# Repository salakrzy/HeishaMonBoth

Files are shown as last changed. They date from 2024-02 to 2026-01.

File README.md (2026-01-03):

# HeishaMonBoth Ver 3.9_a changelog

* Stability and performance improvements.

* When the RJ45cable i connected and the Ethernet interface has got IP address the WiFi interface is go down to reduce power consumpion.

* Automatic selection of a strongest signal if the network uses APs with the same SSID or the network is of the MESH type.

* Changing the flash memory partition table to follow backtrace errors messages.

* Compatibile Integration ver 3.9 with HomeAssistant  [https://github.com/kamaradclimber/heishamon-homeassistant/](https://github.com/kamaradclimber/heishamon-homeassistant/)

## 485 Modbus

* To reduce modbus errors now Modbus port run on hardware UART and logingmessages are redirected to SoftwareSerial port.

* On begining the RxD0 and TxD0 are used to UART0 Rx and Tx. When checkbox Modbus in settings is set to On the hrdware UART0 is redirected to GPIO23 (Rx) and GPIO21(Tx).

* The register definitions of the MOdbus device are user-configurable and stored in the ESP32 flash memory.
  You can download MOdbusxx.json file with your own counters definition to the flash memory in Modbus section.

## New and Old PCB

This 3.9_a version is compatible with both the old and new PCB versions. Settings allows you to configure which board version the software will work with.

Default configuration is set to newPCB.

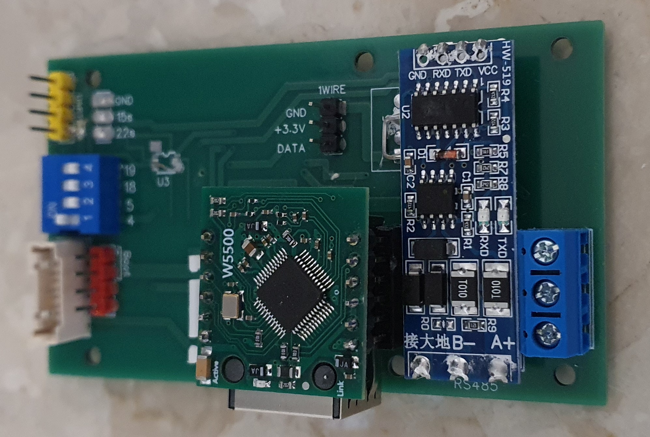
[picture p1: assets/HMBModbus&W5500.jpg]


#### The new PCB works with:

* W5500 Ethernet module
* RS485 to TTL module
* Dallas DS1820 temperature sensor
* I2C Display (only MODBUS version under construction)
* two S0 pins

#### The new board can be:

* powered via USB-C
* mounted in a dedicated enclosure (stl files are in Doc section )
* mounted in a 54mm DIN rail enclosure

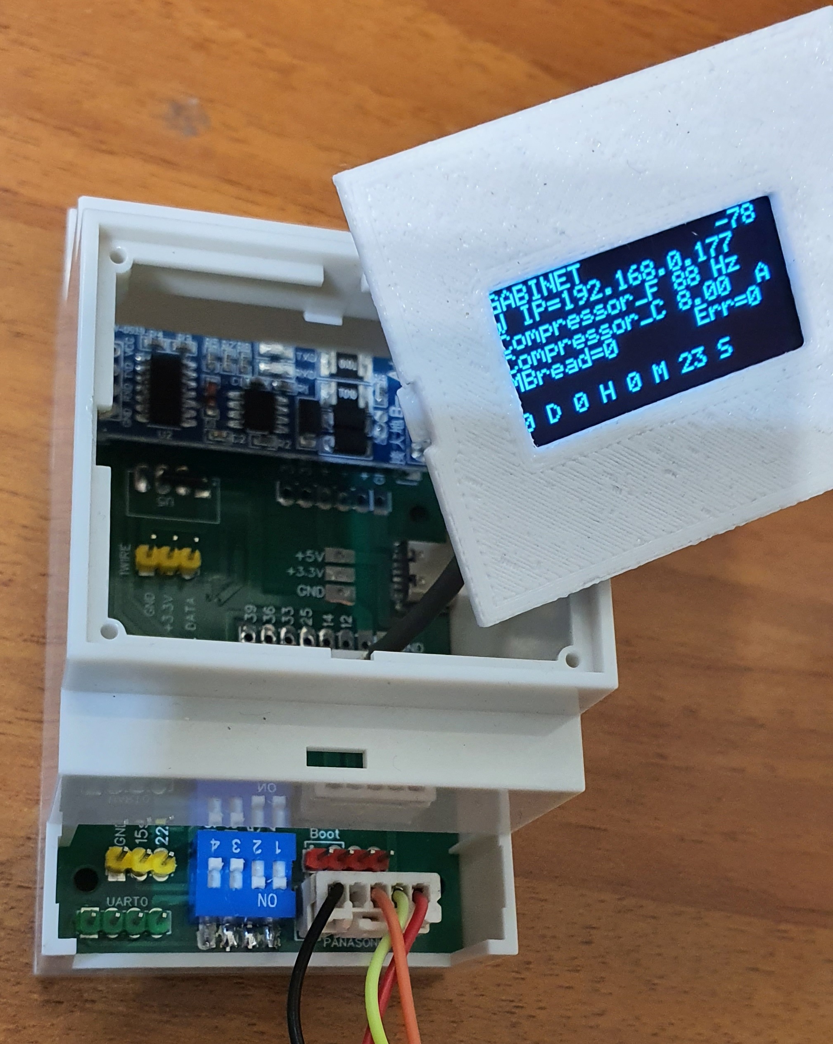
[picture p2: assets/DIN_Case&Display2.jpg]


#### The new PCB with HMBModbus software can communicate with wall control panels via Modbus.

The HMBModbus software has implemented the IntenesisBox PAW-AW-MBS-H interface messages and full TOP and SET HeishaMon Topics.
The description of the Modbus registers that can be used can be found in the /DOC/newPCB tab.

# HeishaMonBoth Ver 3.9 changelog

### ## Version 3_9 supports 12 new parameters.

"Z1_Valve_PID",            //TOP127
"Z2_Valve_PID",            //TOP128
"Bivalent_Control",        //TOP129
"Bivalent_Mode",           //TOP130
"Bivalent_Start_Temp",     //TOP131
"Bivalent_Advanced_Heat",  //TOP132
"Bivalent_Advanced_DHW",   //TOP133
"Bivalent_Advanced_Start_Temp",//TOP134
"Bivalent_Advanced_Stop_Temp",//TOP135
"Bivalent_Advanced_Start_Delay",//TOP136
"Bivalent_Advanced_Stop_Delay",//TOP137
"Bivalent_Advanced_DHW_Delay",//TOP138

### ## Version 3.9 supports meters with MODBUS interface.

The user can define support for up to 4 MODBUS devices. Details on how to connect the interface and define register reading are included in the ModbusDoc folder. Currently, readings are visible in the Console tab and sent to the MQTT server. Readings are performed every 10 seconds (MODBUS_READ_TIMER = 10).If there are any needs for changes, please report them in Issues.

---

# HeishaMonBoth Ver 3.8 changelog

## GPIO

The new PCB version provides additional PINs GPIO (05, 12,14, 18,19, 21 Schmitt trigger,25, 33, 34, 35).
The S0 and S1 Counters  (GPIO 22 and 23) are Schmitt triggered.\

## Upgrade from old versions

New firmware is  backward compatible with the previous PCB version. You can install version 3.8 on the previous PCB version, of cource the functionalities requiring access to the added GPIOs will not be available.
After upgrading firmware to version 3_8 , you should short the "boot" pins for 10 seconds to delete the old configuration settings file. Switch power off, leave boot jumper and after power restart, the new configuration file will be created with a structure compatible with firmware version 3_8 . The boot jumper you can see at the [picture](https://github.com/salakrzy/HeishaMonBoth/blob/main/Doc/Board%20set%20in%20Boot%20or%20Reset%20mode.jpg) in Doc directory.
You can delete old configuration also from the Settings web page, selecting [Factory Reset](https://github.com/salakrzy/HeishaMonBoth/blob/main/Doc/HMBv3_8Stetting2.png) option.
The new file has default parameter settings so you should configure the board again according to your settings.

## Reset configration

If you have problem with WiFi setting after e.g. replace router you can reset the old configuration in this same way.

## Version 3_8 supports 13 new model configurations

"IDU:WH-SDC0509L3E5 ODU:WH-WDG09LE5", //38
"IDU:WH-SDC12H9E8 ODU:WH-UD12HE8", //39
"IDU:WH-SDC0309K3E5, ODU:WH-UDZ07KE5", //40
"IDU:WH-ADC0916H9E8, ODU:WH-UX16HE8", //41
"IDU:WH-ADC0912H9E8, ODU:WH-UX12HE8", //42
"WH-MXC16J9E8", //43
"WH-MXC12J6E5", //44
"IDU:WH-SQC09H3E8, ODU:WH-UQ09HE8", //45
"IDU:WH-ADC0309K3E5 ODU:WH-UDZ09KE5", //46
"IDU:WH-ADC0916H9E8, ODU:WH-UX12HE8", //47
"IDU:WH-SDC0509L3E5 ODU:WH-WDG07LE5", //48
"IDU:WH-SXC09H3E5, ODU:WH-UX09HE5", //49
"IDU:WH-SXC12H9E8, ODU:WH-UX12HE8", //50

## Version 3_8 supports 12 new parameters.

"Water_Pressure",          //TOP115
"Second_Inlet_Temp",       //TOP116
"Economizer_Outlet_Temp",  //TOP117
"Second_Room_Thermostat_Temp",//TOP118
"Bivalent_Heating_Start_Temperature",//TOP119
"Bivalent_Heating_Parallel_Adv_Starttemp",//TOP120
"Bivalent_Heating_Parallel_Adv_Stoptemp",//TOP121
"Bivalent_Heating_Parallel_Adv_Start_Delay",//TOP122
"Bivalent_Heating_Parallel_Adv_Stop_Delay",//TOP123
"Bivalent_Heating_Setting",//TOP124
"2_Zone_mixing_valve_1_opening",//TOP125
"2_Zone_mixing_valve_2_opening",//TOP126

## Home Assistant

This version is compatible with ver 1.13.7 HA Integration [kamaradclimber](https://github.com/kamaradclimber/heishamon-homeassistant)

## RJ45 Ethernet functionality

The 3.8 version support [W5500](https://github.com/salakrzy/HeishaMonBoth/blob/main/Doc/Connecting%20%20W5500%20Ethernet%20module.PNG) module to connetct via RJ45 ethernet cable network
//W5500 ETH pins	-->	ESP32 GPIO
#define ETH_CS    -->      25
#define ETH_IRQ    -->     33
#define ETH_RST    -->     35

//W5500  SPI pins	-->	ESP32 GPIO
#define ETH_SPI_SCK   -->  14
#define ETH_SPI_MISO  -->  34
#define ETH_SPI_MOSI  -->  12

## Notes

Some ESP32 processor versions have only 1 core instead of 2. You have to pay attention to this because the HeishaMonBoth software requires 2 processors. I bought a 1-core processor and wasted some time trying to figure out why the board resets on startup.
OpenTherm and Optional PCB and Rules features should work but havn't been tested.
Oficial published Librrary OneWire has the error in file **OneWire_direct_gpio.h** It is described there https://github.com/PaulStoffregen/OneWire/pull/134/commits/da50f912a8282dacf381d006e75e0141df2a931c)
I recomend use the file **OneWire_direct_gpio.h** from direcotry OneWire\util.

---

# HeishaMonBoth 3.2 changelog

This is a HeishaMon modification allowing parallel work of Panasonic Web, local reading via MQTT and integration with HomeAssistant.
Funtionality of this version fulfil the HeishaMon release v3.2.3
This solution works on ESP32.
This version of the software does support Dallas sensors and two S0 counters.
Integration with HomeAssistant is identical to the original HeishaMon interface. https://github.com/kamaradclimber/heishamon-homeassistant/

Since not all esp32 modules (e. g. esp32u) have IO9 and IO10 outputs and lack of these outputs on DEV boards,
I decided to redesign the PCB and adjust the program code. The new PCB has e few modifications improving functionality.
The program code is adapted to the change of the board and has fixes for the stability of work.
In the /piotools directory there is a simple program HP_Panasonic_Simul.ino that can be uploaded e. g. on Arduino Nano for test.

# Good Luck

IMPORTANT !!!!!!! put your sensitive data to platformio_user_env_sample.ini and rename to platformio_user_env.ini

Special thanks to :
Igor Ybema https://github.com/Egyras/HeishaMon
and
Alexander Gregor-Samosir https://github.com/gregor-samosir/HeishaMonKaskade
for their projects that inspired me to write this modification.

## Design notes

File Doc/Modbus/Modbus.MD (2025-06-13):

# Modbus is the new module of HeishaMonBoth interface for RTU Modbus devices like Power Meter, Water Meter e.g.

This Module use additional board to convert the RS485 RTU Modbus to RS232 Serial UART signals.

By default the MODBUS converter interface use the hardware UART0 port, however this requires block in the Settings  the sending of logs to this port

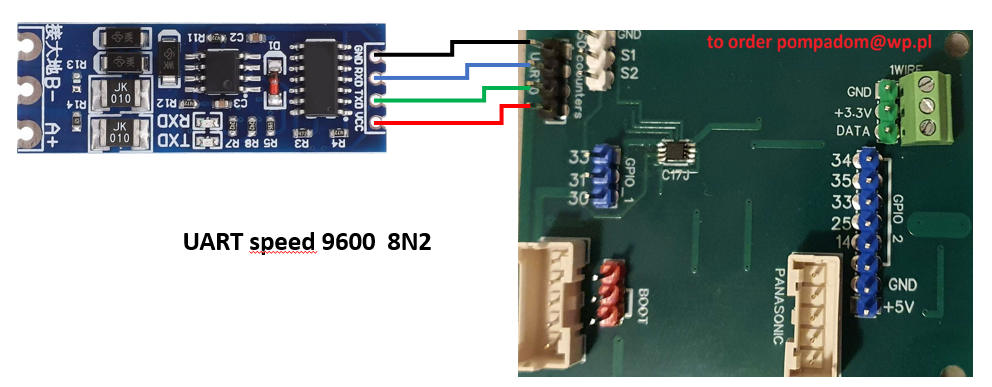
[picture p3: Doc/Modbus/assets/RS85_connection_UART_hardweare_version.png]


> 

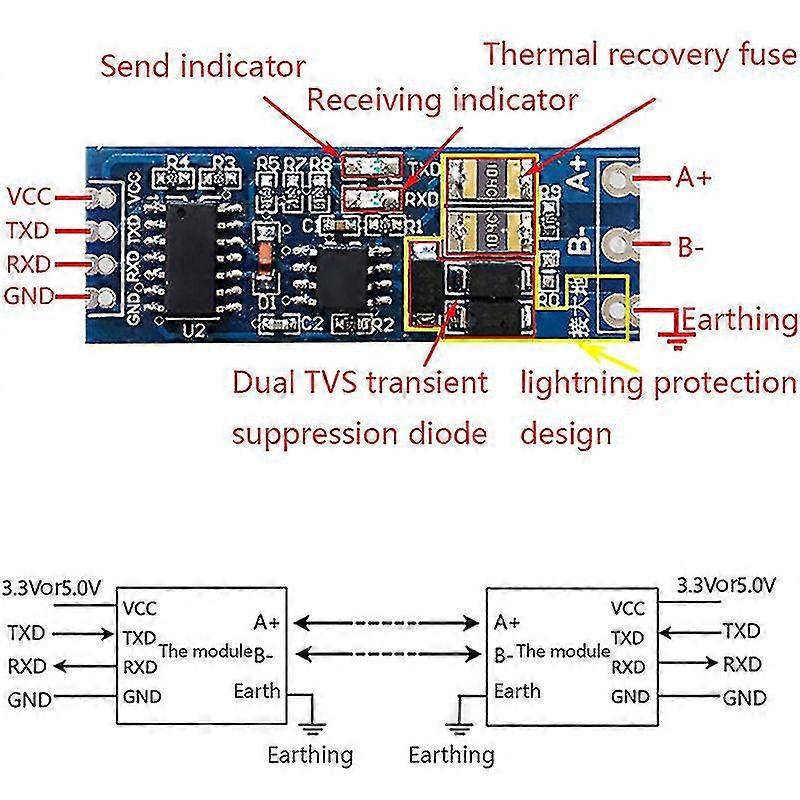
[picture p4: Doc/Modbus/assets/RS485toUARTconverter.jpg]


The Modbus module can use the "EspSoftwareSerial" librrary to create additional serial port to connect the RS485 converter to HeishModBoth. Use SoftwareSerial need a few changes in code The transmission modbus Device parametters must be set to speed -**9600**, bits -**8**, parity -**None**, stop bits -**2** (**9600 8N2** ) and modbus device address must be set this same as the parameter "devAddress" in Modbusxxx.json config file. The software solution seems to be not enough efficient for communication at a speed of 9600 bps. The SoftwareSerial solution from time to time return error modbus device reading when ESP32 processor is bussy by other process eg. webserwer or acounting S0 impulses.
Example how use ESPSeoftwareSerial librrarry is explained in branch ModbusSoft.
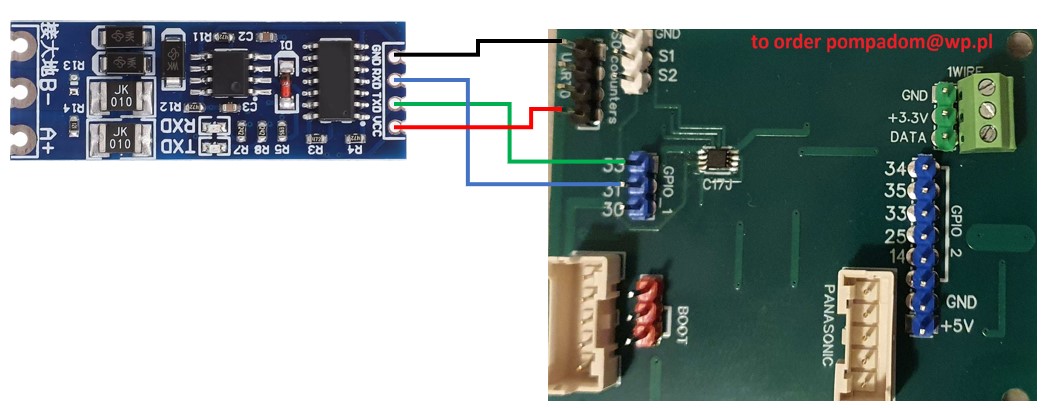
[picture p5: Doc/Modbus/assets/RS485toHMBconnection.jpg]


From the 3.8.1 verison, HeishaMonBoth allows send and handling up to 4 queries to the same device or up to 4 different Modbus devices connected to this same bus, depending what the device address is set by parameter "devAddress". Each Modbusxxx.json file define one query and his name must start from Modbus  word eg Modbus12.json, Modbus3new,json. Each query allows handling up to 16 measured values from the device response. So you can read 16 values from each 4 different devices, 64 values from 1 device or any other combinations defined by the user. The user can define queries for non-standard devices by himself using the description of how to create and upload modbusxxx.json files to the board. The software supports up to 4 Modbusxxx.json files, if more than 4 counter definitions are uploaded only the first 4 will be used and the rest will be ignored.

For convenience and to check the correctness of the definition, it is worth using Online tools to verify the correctness of the JSON file

[**JSON-deserialize-online**](https://codebeautify.org/json-deserialize-online)

and also to serialize the JSON file to reduce the size of the definition file saved in the ESP32 processor memory.

[**JSON-serialize-online**](https://codebeautify.org/json-serialize-online)
In this directory you can find the typical JSON definition file named "Modbus1_example.json" and compact version named "modbus1.json".

In one query, you can read the number of registers defined in "numb_registers" from the address defined by the "addrstart" parameter. The registers in the response appear one after another and there can be up to 120 of them in one query. From these max 120 registers, you can select max 16 registers corresponding to the values that you want to pass to the MQTT server. Each value that is to be passed to the MQTT server has a defined parameter "address" that specifies the address of the register in the device's response.

## How to define the new modbus devices addres, queries and MQTT topics in Modbusxxx.json file

```
"addrstart": 0,			Address first register to read
"numb_registers": 59,		Number registers to read ( counted from 0 as array elements)
"mqttTopic": "L3F1946-P6",	Counter name set the device topic on MQTT server
"datasize1": 4,			Number bytes to read for one register (now only 4 for  float )
"devAddress": 5,		Modbus counter address, must be set this same on the Modbus device
"Value0": {			THIS PARAMETER CAN'T BE CHANGED
"address": 0,			register number position in Modbus device answer 
"divider": 1,			value divider 
"unit": "V",			Value units  {V,A, kWh, Hz, m3 any other this is just only description)
"name": "VoltageA"		*Value name ( Any string )*
},
"Value1": {			THIS PARAMETER CAN'T BE CHANGED
"address": 1,			register number position in Modbus device answer 
"divider": 1,			value divider 
"unit": "V",			Value units  {V,A, kWh, Hz, m3 any other - it is just only description)
"name": "VoltageB"		*Value name ( Any string )*
},
"Value2": {
"address": 2,
"divider": 1,
"unit": "V",
"name": "VoltageC"

......
"Value15": {
"address": 27,
"divider": 1,
"unit": "kWh",
"name": "Production"
}
}
```

JSON Compact serialized form look like this

```
{"addrstart":0,"numb_registers":59,"mqttTopic":"L3F1946-P6","datasize1":4,"devAddress":5,"Value0":{"address":0,"divider":1,"unit":"V","name":"VoltageA"},"Value1":{"address":1,"divider":1,"unit":"V","name":"VoltageB"},"Value2":{"address":2,"divider":1,"unit":"V","name":"VoltageC"},"Value3":{"address":3,"divider":1,"unit":"V","name":"VoltageAB"},"Value4":{"address":4,"divider":1,"unit":"V","name":"VoltageAC"},"Value5":{"address":5,"divider":1,"unit":"V","name":"VoltageBC"},"Value6":{"address":6,"divider":1,"unit":"A","name":"CurrentA"},"Value7":{"address":7,"divider":1,"unit":"A","name":"CurrentB"},"Value8":{"address":8,"divider":1,"unit":"A","name":"CurrentC"},"Value9":{"address":21,"divider":1,"unit":"W","name":"PowerA"},"Value10":{"address":22,"divider":1,"unit":"kW","name":"PowerB"},"Value11":{"address":23,"divider":1,"unit":"kW","name":"PowerC"},"Value12":{"address":24,"divider":1,"unit":"kW","name":"TotalPow"},"Value13":{"address":25,"divider":1,"unit":"Hz","name":"Frequency"},"Value14":{"address":26,"divider":1,"unit":"kWh","name":"Consumption"},"Value15":{"address":27,"divider":1,"unit":"kWh","name":"Production"}}
```

You can fulfil the Modbus1_example.json decribing your device and values and use serialize online tool to convert JSON file to the **Compact** form.

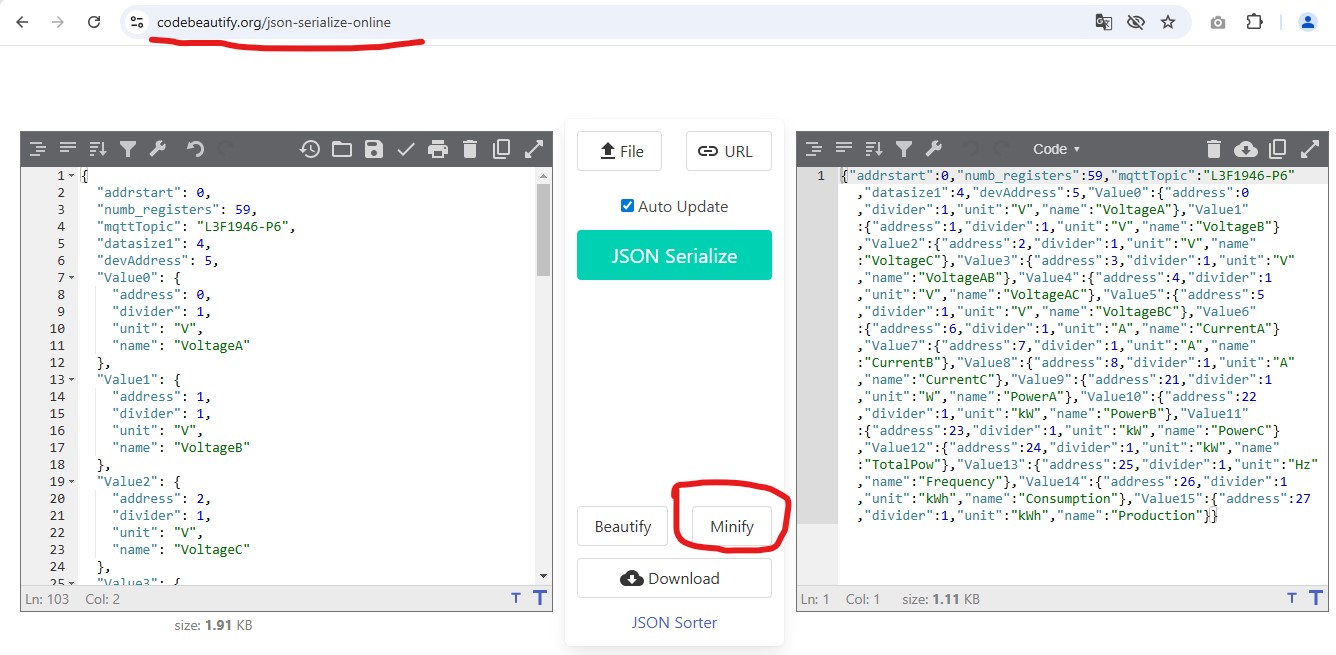
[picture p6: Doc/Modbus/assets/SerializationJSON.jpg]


Next you can upload Modbusxxx.json file using Upload function.

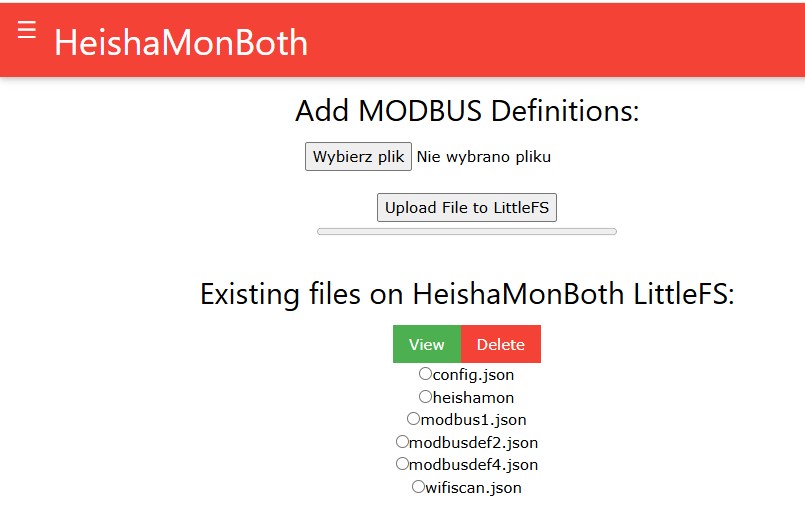
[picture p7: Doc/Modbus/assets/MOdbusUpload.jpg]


After this you can view or delete uploaded file.
If everything looks OK, You should run Reboot option to reload Modbus devices definitions. View the config.json file is forbiden to protect the wifi password but it is possibel to delete all shown files. If you delete all shown files it take this same effect as the factory reset.

##### Attention!!!

To ensure the restoration of communication with the Board in the event of continuous restarts due to an incorrectly defined counter pattern, a mechanism has been introduced to reset the settings to factory values in the event of a "Panic" error during system startup. In this case You should set the Wifi SSID, password, MQTT server and other configuration parameters.

You can view the meter readings in the console tab on the HeishaMonBoth website.

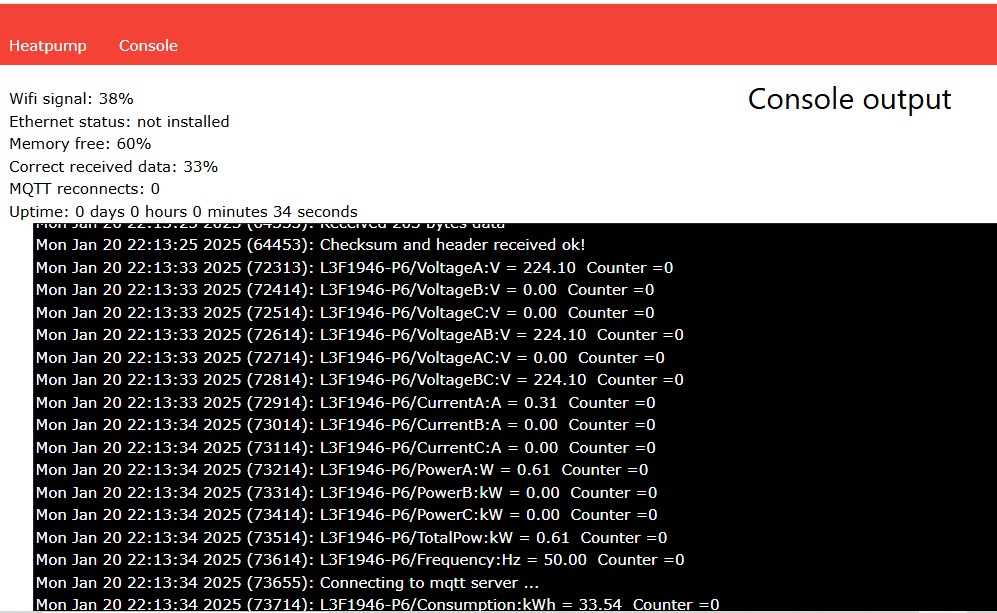
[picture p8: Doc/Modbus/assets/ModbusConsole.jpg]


You can also view them on an MQTT server.

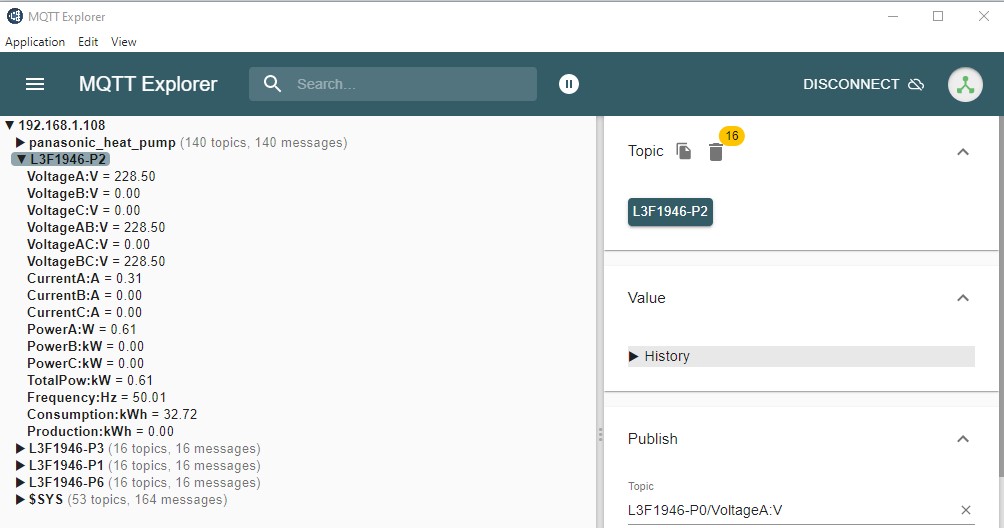
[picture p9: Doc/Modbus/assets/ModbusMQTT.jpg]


### I encourage you to report any bugs you discover or suggestions for improving the functionality of the HeishaMonBoth interface in the Issue section.

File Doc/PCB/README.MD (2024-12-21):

         
How to use：

At editor EasyEDA https://u.easyeda.com , 
Creata new project,open the document via: Top menu - File - Open - EasyEDA... , and select the json file, then open it at the editor, you can save it into a project.

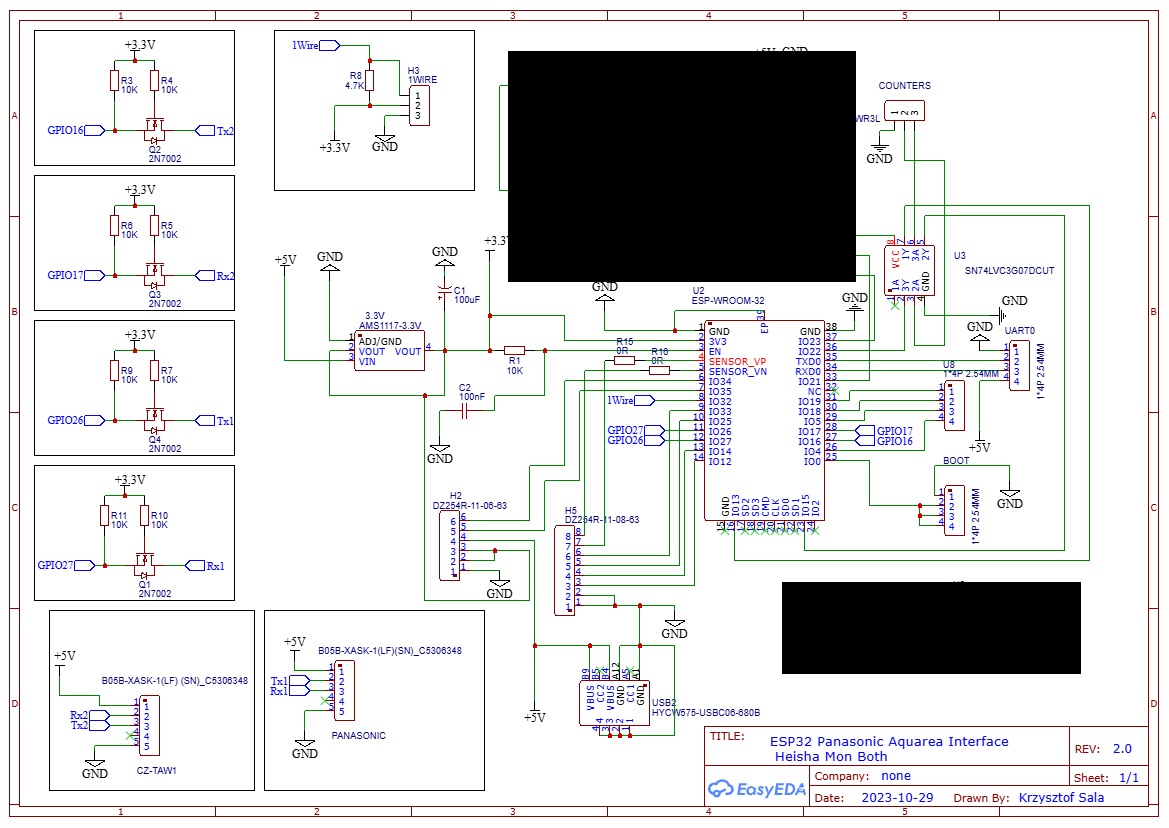
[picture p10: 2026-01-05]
Doc/new PCB/Schematic_Panasonic-aquarea-to-cztaw_W5500noRS485.jpg

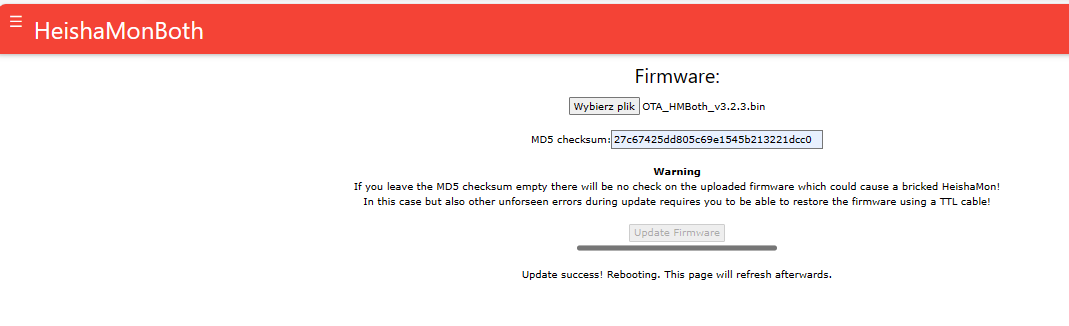
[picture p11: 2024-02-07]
Doc/HeishaMonBoth Firmware Update.png

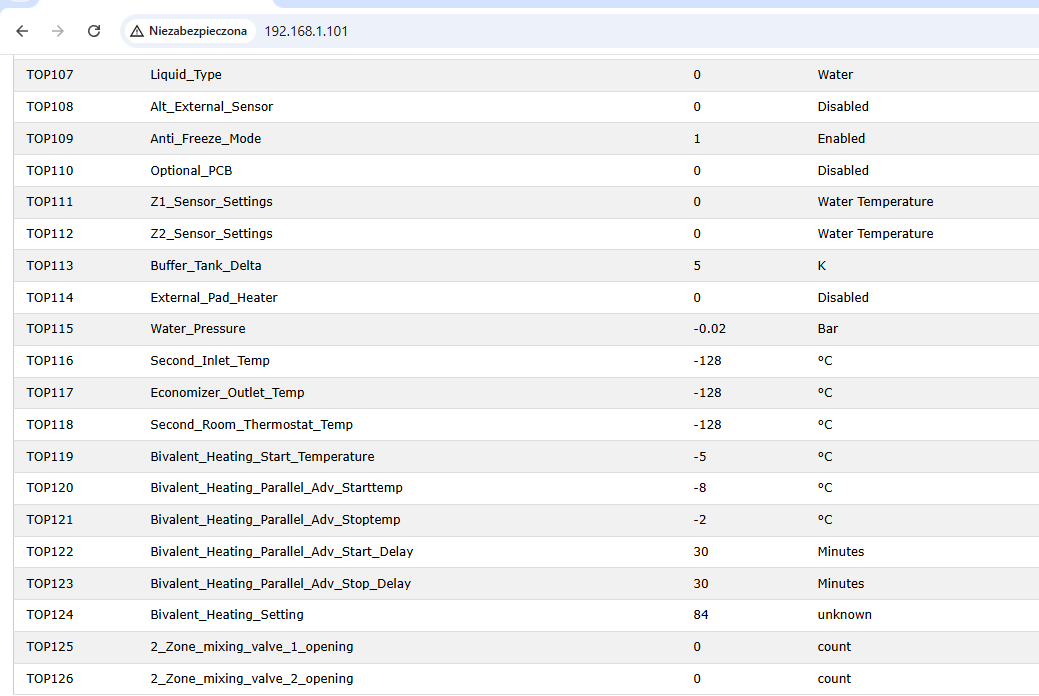
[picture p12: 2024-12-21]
Doc/HMBv3_8Topics2.PNG

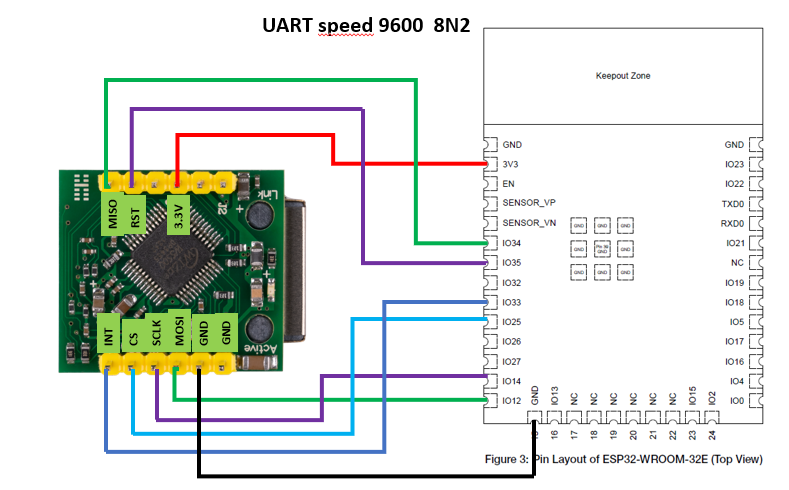
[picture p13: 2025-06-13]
Doc/new PCB/W5500 connections.png

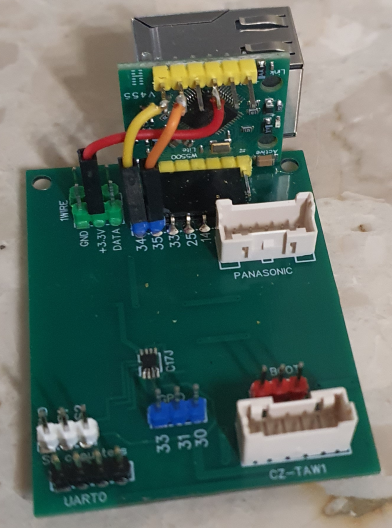
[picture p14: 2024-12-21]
Doc/W5500 Ethernet connection/Connecting W5500 Ethernet module.PNG

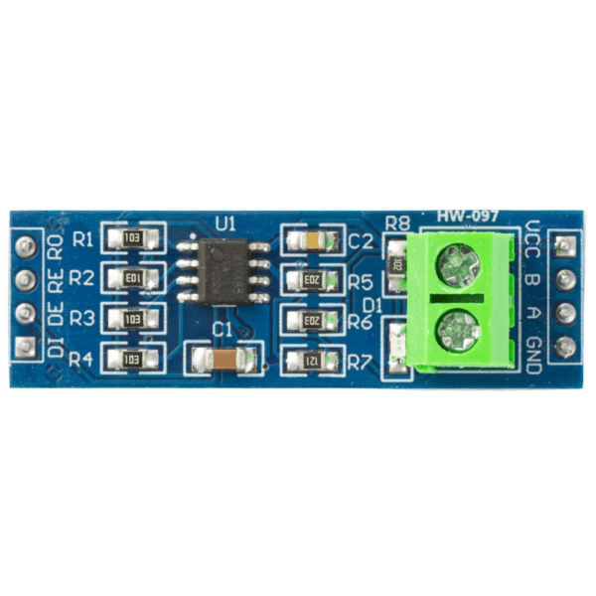
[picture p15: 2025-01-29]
Doc/Modbus/assets/RS485wDEREcontrol.png

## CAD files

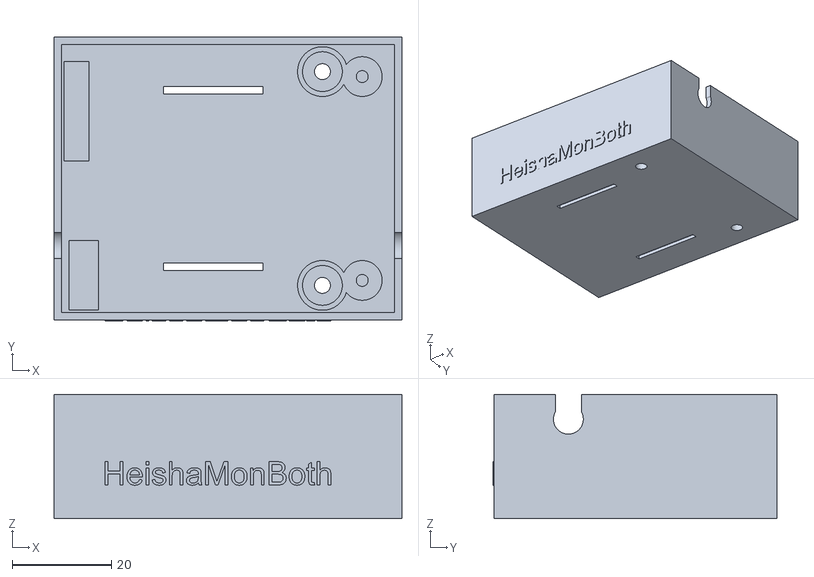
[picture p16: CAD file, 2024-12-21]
Doc/3DCase/BotHeishaMonBoth.stl
70.0 x 57.2 x 25.0

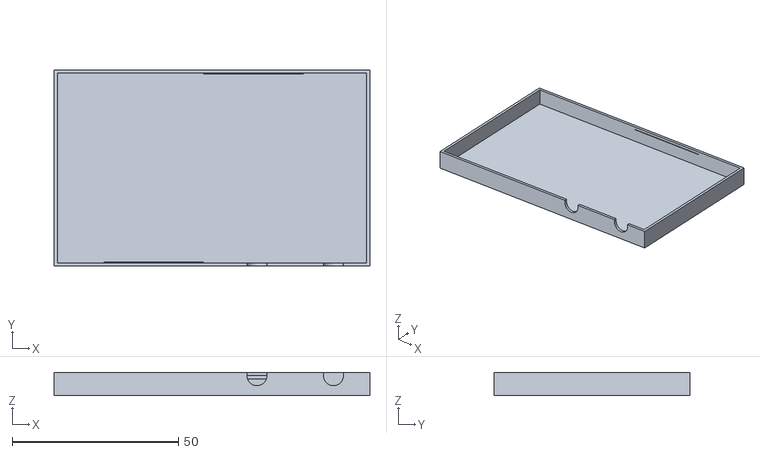
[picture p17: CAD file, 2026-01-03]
Doc/new PCB/3DCase/MHMB_Top.stl
95.0 x 59.0 x 7.00

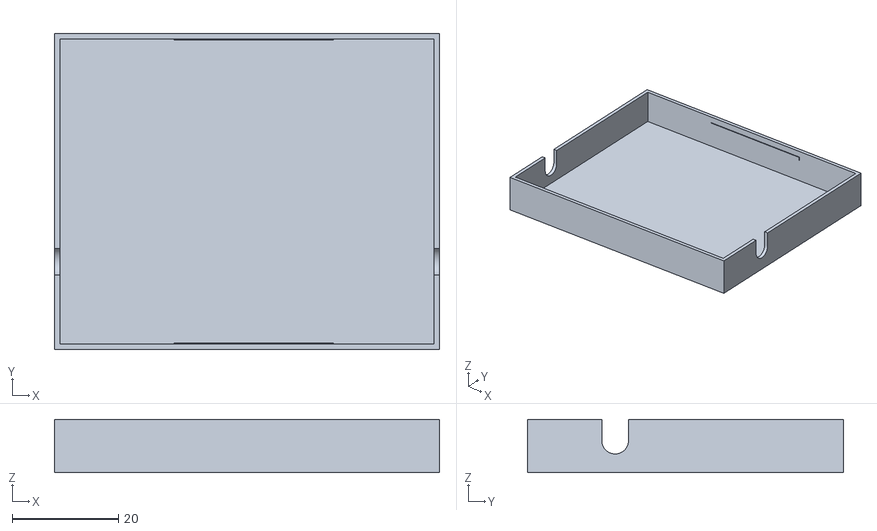
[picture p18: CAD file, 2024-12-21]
Doc/3DCase/TopHeishaMonBoth.stl
72.5 x 59.5 x 10.0

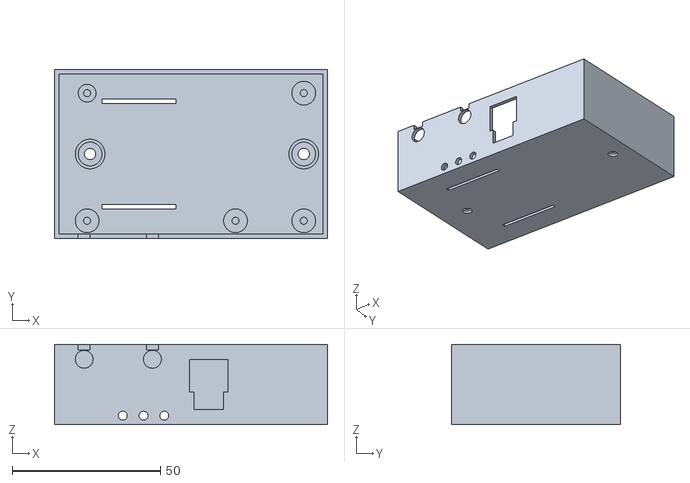
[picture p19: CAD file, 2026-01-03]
Doc/new PCB/3DCase/MHMB_Bottom.stl
92.0 x 57.0 x 27.0

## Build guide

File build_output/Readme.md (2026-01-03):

# under windows

run **OTA_flash.bat**

or
run console **CMD**
and run command

##### **esptool.exe -p COM7 --before default_reset --after hard_reset --chip esp32  write_flash --flash_mode dio --flash_size detect --flash_freq 40m 0x1000 bootloader.bin 0x8000 partitions.bin 0x10000 firmware\UART_HMBoth_v3_2_3.bin 0x00391000 littlefs.bin**

or  if you prefer Python

##### **pip install esptool**

##### **python esptool.py -p COM7 --before default_reset --after hard_reset --chip esp32  write_flash --flash_mode dio --flash_size detect --flash_freq 40m 0x1000 bootloader.bin 0x8000 partitions.bin 0x10000 UART_HMBoth_v3_2_3.bin 0x00391000 littlefs.bin**

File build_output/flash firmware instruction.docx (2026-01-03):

Flash firmware to HeishaMonBoth board

1. Upgrade file by Webserwer

Go to Setting > Firmware

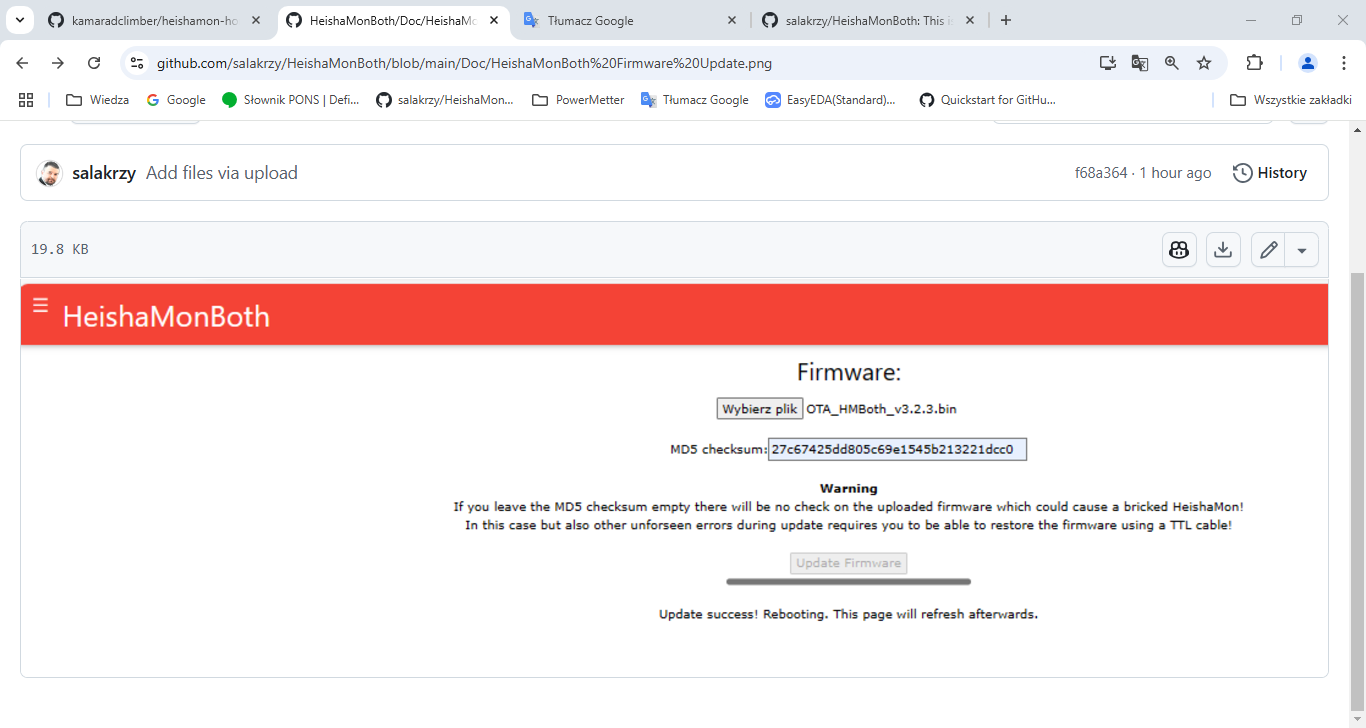
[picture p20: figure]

2. Using USB to TTL Serial converter

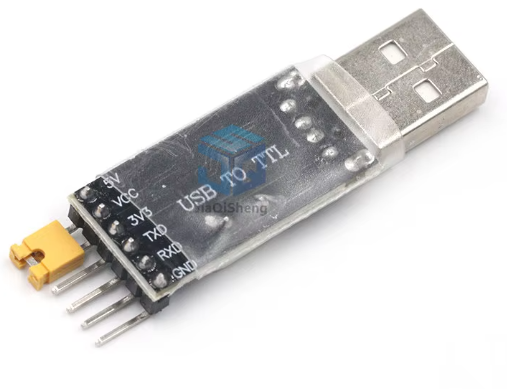
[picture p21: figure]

Copy the directory https://github.com/salakrzy/HeishaMonBoth/tree/main/build_output to your computer

Close “boot” pins on the board and connect the “ UART0” pins with USB converter.

Disconnect board from Heat pump!!!! Power will be provided by converter.

Remember Tx pin from board goes to Rx pin in converter and Rx from board goes to Tx.

Connect only the Tx, Rx, GND and +5V pins.

Go to the local directory and run OTA_flash.bat

You could see something like this

esptool.py v2.3.1

Connecting........_____....._____....._____.....___

Chip is ESP32D0WDQ5 (revision (unknown 0xa))

Features: WiFi, BT, Dual Core, Embedded Flash, VRef calibration in efuse

Uploading stub...

Running stub...

Stub running...

Changing baud rate to 921600

Changed.

Configuring flash size...

Auto-detected Flash size: 4MB

Compressed 18928 bytes to 13069...

Wrote 18928 bytes (13069 compressed) at 0x00001000 in 0.2 seconds (effective 809.8 kbit/s)...

Hash of data verified.

Compressed 3072 bytes to 157...

Wrote 3072 bytes (157 compressed) at 0x00008000 in 0.0 seconds (effective 1536.0 kbit/s)...

Hash of data verified.

Compressed 1102304 bytes to 665904...

Wrote 1102304 bytes (665904 compressed) at 0x00010000 in 9.4 seconds (effective 937.4 kbit/s)...

Hash of data verified.

Compressed 57344 bytes to 722...

Wrote 57344 bytes (722 compressed) at 0x00391000 in 0.0 seconds (effective 28671.9 kbit/s)...

Hash of data verified.

Leaving...

Hard resetting via RTS pin...

d:\...\...\Flash HeishamonBoth>pause

Press any key to continue . . .

Disconnect boot jumper and restart power

You can clear all ESP32 flash memory using command eraseesp.bat

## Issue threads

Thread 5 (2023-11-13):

Intergrate into heishamon release

IgorYbema, 2023-11-13:
Hi,
Thank you for the great work! The idea of chaining the CZ-TAW1 through heishamon is something which was thought before earlier but never implemented due to lack of GPIO's. Never had time to change the code to an ESP32 style but you have done this already. Great!

I hope you don't mind that I'll take your changes into a future release of heishamon and a redesign of the pcb to add the connector.

Misiu, 2023-11-22:
@IgorYbema any updates on this?
Also, do you plan to do PR to https://github.com/Egyras/HeishaMon or in your fork?
I just got my heat pump installed and I would like to add it to Home Assistant, so I wondering if should I wait for a new PCB or order the old one.

salakrzy, 2023-11-29:
Hello,
I'm glad you like the idea. Of course anyone who wants can use, copy and publish the result of my work on this interface. Thank you for every star clicked for this project;-)

I have a few HeishaMonBoth interface PCBs.  If you are interested in shipping, please send an email to [pompadom@wp.pl]
The assembled interface looks like in the attached pictures.

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

salakrzy, 2023-11-29:
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

IgorYbema, 2024-02-25:
Hi,
I have made a modified heishamon with this and ordered some test boards. Hopefully they work and I can use your code on them and start integrating your changes into the main project. One question, did you run into any problems with the CZTAW connected to your board and both being powered from the heatpump?

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

Closed 2023-11-29.

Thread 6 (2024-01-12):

Can not connect to Wifi with Wemos ESP32 board

ElVit, 2024-01-12:
Hi,

as the title says it I can not connect to the WiFi if I flash HeishamonBoth.
I use a Wemos ESP32 board (MH-ET LIVE MiniKit for ESP32).
If I flash a different firmware e.g. for ESPHome I can connect to my WiFi without any issues,
so my hardware should not be the problem here.

I flashed the firmware from `/build_output/firmware/ESP_USBv3.2.3.bin` with the [esptool](https://github.com/espressif/esptool) like so:
- ./esptool -p COM5 erase_flash
- ./esptool -p COM5 -b 460800 write_flash 0x00000 esp32_bootloader_v4.bin
- ./esptool -p COM5 -b 460800 write_flash 0x10000 ESP_USBv3.2.3.bin

The esp32_bootloader_v4.bin I took from the [WLED repo](https://github.com/Aircoookie/WLED/releases/download/v0.13.1/esp32_bootloader_v4.bin).

I could also flash the HeishaMonBoth firmware with the ESPHomeFlasher, but connecting to the WiFi is still failing.

Here my log output while I try to connect to the WiFi:
```
Using 'COM5' as serial port.
Showing logs:
[14:34:52]Thu Jan  1 00:00:15 1970 (15239): Previous read data attempt failed due to timeout!
[14:34:52]Thu Jan  1 00:00:15 1970 (15239): Received 0 bytes data
[14:34:52]Thu Jan  1 00:00:15 1970 (15250): sent bytes: 8 including checksum value: 185 source; 1
[14:34:52]
[14:34:52]Thu Jan  1 00:00:15 1970 (15250): Requesting initial start query
[14:34:54]Thu Jan  1 00:00:17 1970 (17251): Previous read data attempt failed due to timeout!
[14:34:54]Thu Jan  1 00:00:17 1970 (17251): Received 0 bytes data
[14:34:54]Thu Jan  1 00:00:17 1970 (17262): sent bytes: 8 including checksum value: 185 source; 1
[14:34:54]
[14:34:54]Thu Jan  1 00:00:17 1970 (17262): Requesting initial start query
[14:34:54]Thu Jan  1 00:00:17 1970 (17573): Heishamon stats: Uptime: 0 days 0 hours 0 minutes 17 seconds ## Free memory: 79% ## Heap fragmentation: % ## Max free block:  bytes ## Free heap: 226532 bytes ## Wifi: -1% (RSSI: 0) ## Mqtt reconnects: 0 ## Correct data: 0.00%
[14:34:54]Thu Jan  1 00:00:17 1970 (17594): Requesting new panasonic data
[14:34:54]Thu Jan  1 00:00:17 1970 (17594): Already sending data. Buffering this send request
[14:34:56]Thu Jan  1 00:00:19 1970 (19263): Previous read data attempt failed due to timeout!
[14:34:56]Thu Jan  1 00:00:19 1970 (19263): Received 0 bytes data
[14:34:56]Thu Jan  1 00:00:19 1970 (19274): sent bytes: 8 including checksum value: 185 source; 1
[14:34:56]
[14:34:56]Thu Jan  1 00:00:19 1970 (19274): Requesting initial start query
[14:34:58]Thu Jan  1 00:00:21 1970 (21275): Previous read data attempt failed due to timeout!
[14:34:58]Thu Jan  1 00:00:21 1970 (21275): Received 0 bytes data
[14:34:58]Thu Jan  1 00:00:21 1970 (21286): sent bytes: 8 including checksum value: 185 source; 1
[14:34:58]
[14:34:58]Thu Jan  1 00:00:21 1970 (21286): Requesting initial start query
[14:34:59]Thu Jan  1 00:00:22 1970 (22573): Heishamon stats: Uptime: 0 days 0 hours 0 minutes 22 seconds ## Free memory: 79% ## Heap fragmentation: % ## Max free block:  bytes ## Free heap: 226532 bytes ## Wifi: -1% (RSSI: 0) ## Mqtt reconnects: 0 ## Correct data: 0.00%
[14:34:59]Thu Jan  1 00:00:22 1970 (22594): Requesting new panasonic data
[14:34:59]Thu Jan  1 00:00:22 1970 (22595): Already sending data. Buffering this send request
[14:35:00]Thu Jan  1 00:00:23 1970 (23287): Previous read data attempt failed due to timeout!
[14:35:00]Thu Jan  1 00:00:23 1970 (23287): Received 0 bytes data
[14:35:00]Thu Jan  1 00:00:23 1970 (23298): sent bytes: 8 including checksum value: 185 source; 1
[14:35:00]
[14:35:00]Thu Jan  1 00:00:23 1970 (23298): Requesting initial start query
[14:35:02]Thu Jan  1 00:00:25 1970 (25299): Previous read data attempt failed due to timeout!
[14:35:02]Thu Jan  1 00:00:25 1970 (25299): Received 0 bytes data
[14:35:02]Thu Jan  1 00:00:25 1970 (25310): sent bytes: 8 including checksum value: 185 source; 1
[14:35:02]
[14:35:02]Thu Jan  1 00:00:25 1970 (25310): Requesting initial start query
[14:35:04]Thu Jan  1 00:00:27 1970 (27311): Previous read data attempt failed due to timeout!
[14:35:04]Thu Jan  1 00:00:27 1970 (27311): Received 0 bytes data
[14:35:04]Thu Jan  1 00:00:27 1970 (27322): sent bytes: 8 including checksum value: 185 source; 1
[14:35:04]
[14:35:04]Thu Jan  1 00:00:27 1970 (27322): Requesting initial start query
[14:35:04]Thu Jan  1 00:00:27 1970 (27633): Heishamon stats: Uptime: 0 days 0 hours 0 minutes 27 seconds ## Free memory: 79% ## Heap fragmentation: % ## Max free block:  bytes ## Free heap: 226532 bytes ## Wifi: -1% (RSSI: 0) ## Mqtt reconnects: 0 ## Correct data: 0.00%
[14:35:04]Thu Jan  1 00:00:27 1970 (27654): Requesting new panasonic data
[14:35:04]Thu Jan  1 00:00:27 1970 (27654): Already sending data. Buffering this send request
[14:35:06]Thu Jan  1 00:00:29 1970 (29323): Previous read data attempt failed due to timeout!
[14:35:06]Thu Jan  1 00:00:29 1970 (29323): Received 0 bytes data
[14:35:06]Thu Jan  1 00:00:29 1970 (29334): sent bytes: 8 including checksum value: 185 source; 1
[14:35:06]
[14:35:06]Thu Jan  1 00:00:29 1970 (29334): Requesting initial start query
[14:35:08]Thu Jan  1 00:00:31 1970 (31335): Previous read data attempt failed due to timeout!
[14:35:08]Thu Jan  1 00:00:31 1970 (31335): Received 0 bytes data
[14:35:08]Thu Jan  1 00:00:31 1970 (31346): sent bytes: 8 including checksum value: 185 source; 1
[14:35:08]
[14:35:08]Thu Jan  1 00:00:31 1970 (31346): Requesting initial start query
[14:35:09]Thu Jan  1 00:00:32 1970 (32633): Heishamon stats: Uptime: 0 days 0 hours 0 minutes 32 seconds ## Free memory: 79% ## Heap fragmentation: % ## Max free block:  bytes ## Free heap: 226532 bytes ## Wifi: -1% (RSSI: 0) ## Mqtt reconnects: 0 ## Correct data: 0.00%
[14:35:09]Thu Jan  1 00:00:32 1970 (32654): Requesting new panasonic data
[14:35:09]Thu Jan  1 00:00:32 1970 (32655): Already sending data. Buffering this send request
[14:35:10]Thu Jan  1 00:00:33 1970 (33347): Previous read data attempt failed due to timeout!
[14:35:10]Thu Jan  1 00:00:33 1970 (33347): Received 0 bytes data
[14:35:10]Thu Jan  1 00:00:33 1970 (33358): sent bytes: 8 including checksum value: 185 source; 1
[14:35:10]
[14:35:10]Thu Jan  1 00:00:33 1970 (33358): Requesting initial start query
[14:35:11]Thu Jan  1 00:00:34 1970 (34299): New webserver client: 192.168.4.2:51402
[14:35:12]Thu Jan  1 00:00:35 1970 (35359): Previous read data attempt failed due to timeout!
[14:35:12]Thu Jan  1 00:00:35 1970 (35360): Received 0 bytes data
[14:35:12]Thu Jan  1 00:00:35 1970 (35370): sent bytes: 8 including checksum value: 185 source; 1
[14:35:12]
[14:35:12]Thu Jan  1 00:00:35 1970 (35370): Requesting initial start query
[14:35:14]Thu Jan  1 00:00:37 1970 (37371): Previous read data attempt failed due to timeout!
[14:35:14]Thu Jan  1 00:00:37 1970 (37371): Received 0 bytes data
[14:35:14]Thu Jan  1 00:00:37 1970 (37382): sent bytes: 8 including checksum value: 185 source; 1
[14:35:14]
[14:35:14]Thu Jan  1 00:00:37 1970 (37382): Requesting initial start query
[14:35:14]Thu Jan  1 00:00:37 1970 (37693): Heishamon stats: Uptime: 0 days 0 hours 0 minutes 37 seconds ## Free memory: 78% ## Heap fragmentation: % ## Max free block:  bytes ## Free heap: 222920 bytes ## Wifi: -1% (RSSI: 0) ## Mqtt reconnects: 0 ## Correct data: 0.00%
[14:35:14]Thu Jan  1 00:00:37 1970 (37714): Requesting new panasonic data
[14:35:14]Thu Jan  1 00:00:37 1970 (37715): Already sending data. Buffering this send request
[14:35:16]Thu Jan  1 00:00:39 1970 (39383): Previous read data attempt failed due to timeout!
[14:35:16]Thu Jan  1 00:00:39 1970 (39383): Received 0 bytes data
[14:35:16]Thu Jan  1 00:00:39 1970 (39394): sent bytes: 8 including checksum value: 185 source; 1
[14:35:16]
[14:35:16]Thu Jan  1 00:00:39 1970 (39394): Requesting initial start query
[14:35:18]Thu Jan  1 00:00:41 1970 (41395): Previous read data attempt failed due to timeout!
[14:35:18]Thu Jan  1 00:00:41 1970 (41395): Received 0 bytes data
[14:35:18]Thu Jan  1 00:00:41 1970 (41406): sent bytes: 8 including checksum value: 185 source; 1
[14:35:18]
[14:35:18]Thu Jan  1 00:00:41 1970 (41406): Requesting initial start query
[14:35:19]Thu Jan  1 00:00:42 1970 (42693): Heishamon stats: Uptime: 0 days 0 hours 0 minutes 42 seconds ## Free memory: 78% ## Heap fragmentation: % ## Max free block:  bytes ## Free heap: 222920 bytes ## Wifi: -1% (RSSI: 0) ## Mqtt reconnects: 0 ## Correct data: 0.00%
[14:35:19]Thu Jan  1 00:00:42 1970 (42715): Requesting new panasonic data
[14:35:19]Thu Jan  1 00:00:42 1970 (42715): Already sending data. Buffering this send request
[14:35:20]Thu Jan  1 00:00:43 1970 (43407): Previous read data attempt failed due to timeout!
[14:35:20]Thu Jan  1 00:00:43 1970 (43407): Received 0 bytes data
[14:35:20]Thu Jan  1 00:00:43 1970 (43418): sent bytes: 8 including checksum value: 185 source; 1
[14:35:20]
[14:35:20]Thu Jan  1 00:00:43 1970 (43418): Requesting initial start query
[14:35:22]Thu Jan  1 00:00:45 1970 (45419): Previous read data attempt failed due to timeout!
[14:35:22]Thu Jan  1 00:00:45 1970 (45419): Received 0 bytes data
[14:35:22]Thu Jan  1 00:00:45 1970 (45430): sent bytes: 8 including checksum value: 185 source; 1
[14:35:22]
[14:35:22]Thu Jan  1 00:00:45 1970 (45430): Requesting initial start query
[14:35:24]Thu Jan  1 00:00:47 1970 (47431): Previous read data attempt failed due to timeout!
[14:35:24]Thu Jan  1 00:00:47 1970 (47431): Received 0 bytes data
[14:35:24]Thu Jan  1 00:00:47 1970 (47442): sent bytes: 8 including checksum value: 185 source; 1
[14:35:24]
[14:35:24]Thu Jan  1 00:00:47 1970 (47442): Requesting initial start query
[14:35:24]Thu Jan  1 00:00:47 1970 (47753): Heishamon stats: Uptime: 0 days 0 hours 0 minutes 47 seconds ## Free memory: 78% ## Heap fragmentation: % ## Max free block:  bytes ## Free heap: 222920 bytes ## Wifi: -1% (RSSI: 0) ## Mqtt reconnects: 0 ## Correct data: 0.00%
[14:35:24]Thu Jan  1 00:00:47 1970 (47774): Requesting new panasonic data
[14:35:24]Thu Jan  1 00:00:47 1970 (47775): Already sending data. Buffering this send request
[14:35:24]Thu Jan  1 00:00:47 1970 (47865): New webserver client: 192.168.4.2:60826
[14:35:25]Thu Jan  1 00:00:48 1970 (48370): Closing webserver client: 192.168.4.2:60826
[14:35:25]Thu Jan  1 00:00:48 1970 (48394): New webserver client: 192.168.4.2:60827
[14:35:26]Thu Jan  1 00:00:49 1970 (49834): Previous read data attempt failed due to timeout!
[14:35:26]Thu Jan  1 00:00:49 1970 (49834): Received 0 bytes data
[14:35:26]Thu Jan  1 00:00:49 1970 (49845): sent bytes: 8 including checksum value: 185 source; 1
[14:35:26]
[14:35:26]Thu Jan  1 00:00:49 1970 (49845): Requesting initial start query
[14:35:29]Thu Jan  1 00:00:52 1970 (52208): Previous read data attempt failed due to timeout!
[14:35:29]Thu Jan  1 00:00:52 1970 (52208): Received 0 bytes data
[14:35:29]Thu Jan  1 00:00:52 1970 (52219): sent bytes: 8 including checksum value: 185 source; 1
[14:35:29]
[14:35:29]Thu Jan  1 00:00:52 1970 (52219): Requesting initial start query
[14:35:30]Thu Jan  1 00:00:53 1970 (53179): Heishamon stats: Uptime: 0 days 0 hours 0 minutes 53 seconds ## Free memory: 75% ## Heap fragmentation: % ## Max free block:  bytes ## Free heap: 212612 bytes ## Wifi: -1% (RSSI: 0) ## Mqtt reconnects: 0 ## Correct data: 0.00%
[14:35:30]Thu Jan  1 00:00:53 1970 (53200): Requesting new panasonic data
[14:35:30]Thu Jan  1 00:00:53 1970 (53201): Already sending data. Buffering this send request
[14:35:30]Thu Jan  1 00:00:53 1970 (53212): Closing webserver client: 192.168.4.2:60827
[14:35:30]Thu Jan  1 00:00:53 1970 (53222): New webserver client: 192.168.4.2:60829
[14:35:31]Thu Jan  1 00:00:54 1970 (54220): Previous read data attempt failed due to timeout!
[14:35:31]Thu Jan  1 00:00:54 1970 (54221): Received 0 bytes data
[14:35:31]Thu Jan  1 00:00:54 1970 (54231): sent bytes: 8 including checksum value: 185 source; 1
[14:35:31]
[14:35:31]Thu Jan  1 00:00:54 1970 (54232): Requesting initial start query
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

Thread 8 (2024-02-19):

MD5 NOT Matched

emjotpe, 2024-02-19:
In Windows PowerShell:
certutil -hashfile UART_HMBoth_v3_2_3.bin MD5
MD5 hash of UART_HMBoth_v3_2_3.bin:
9124d9d4fe943c6bd0320e4bdc46f50e
CertUtil: -hashfile command completed successfully.

salakrzy, 2024-03-26:
thx. now both UARTxxx.bin and OTAxxx.bin  MD5 should be corect.

Closed 2024-03-26.

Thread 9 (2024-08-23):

Hardware Compatibility

Skol6, 2024-08-23:
Hi,

is the HeishamonBoth Software also compatible with original Heisman Board or do I need a new hardware as well?

Regards

salakrzy, 2024-08-23:
HeishaMon uses ESP8266 processor
HeishaMonBoth uses ESP32 processor. They are completely different  processors.
You need differrent hardware.

Closed 2024-08-23.

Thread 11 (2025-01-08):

MD5 checksum again...

emjotpe, 2025-01-08:
MD5 checksum OTA_HMBoth_v3_2_3.bin is 151fdbcad3bb1afa0ba05513b8569156
MD5 checksum UART_HMBoth_v3_2_3.bin is 9124d9d4fe943c6bd0320e4bdc46f50e

salakrzy, 2025-01-20:
You're right, my mistake, sorry, I've already corrected it.

Thank you for the information.

Closed 2025-01-20.

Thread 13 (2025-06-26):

MD5 checksum again...

emjotpe, 2025-06-26:
MD5 hash of UART_HMBoth_v3_9.bin:
503e97c41b08ef86f3e807273fcf79f4

salakrzy, 2025-06-27:
You are right, thank you. The correct MD5 for this file should be 503e97c41b08ef86f3e807273fcf79f4

Closed 2025-06-27.

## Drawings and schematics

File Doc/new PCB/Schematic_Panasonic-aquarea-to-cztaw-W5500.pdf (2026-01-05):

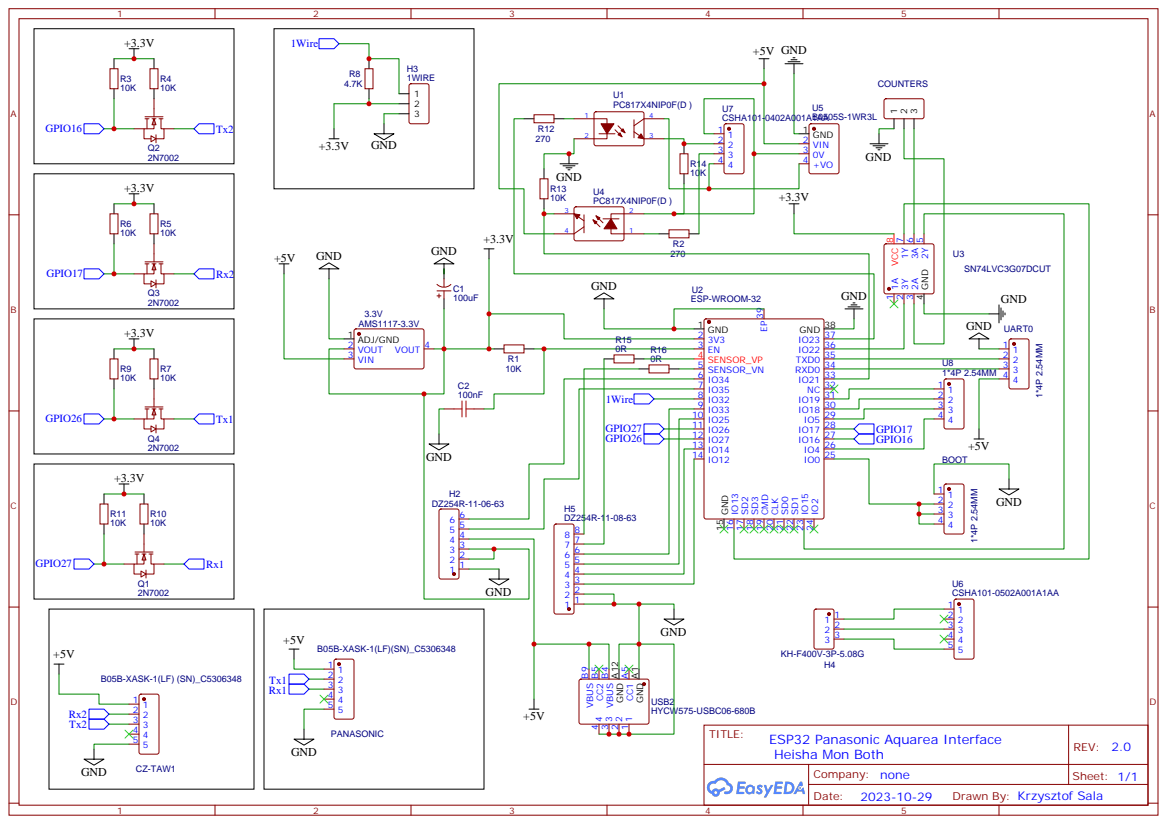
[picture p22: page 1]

Drawn By: Krzysztof Sala

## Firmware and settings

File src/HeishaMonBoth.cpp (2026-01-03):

// you can change Tx and Rx to any GPIO using command Serialx.begin(9600, SERIAL_8E1, Rx,Tx);
//loggingSerial	Serial.begin(115200,SERIAL_8N1,LOGRX,LOGTX); ////####ESP32initial Serial for monitoring
//heatpumpSerial	Serial1.begin(9600, SERIAL_8E1,27,26);    ////####ESP32Serial goes to cn-cnt in Panasonic Heat Pump, 
//proxySerial		Serial2.begin(9600, SERIAL_8E1,16,17);    ////####ESP32Serial2 goes to cz-taw1, 
//for MODBUS     loggingSerial.begin(115200, SWSERIAL_8N1, LOGRX, LOGTX, false,256,128);  LOGRX=23, LOGTX=21,
#include <Arduino.h>
//#define CONFIG_LOG_VERSION_2
#define LOCAL_LOG_LEVEL LOG_LEVEL_ERROR
#include "Logging.h"


#define LOGRX 3
#define LOGTX 1 

#define LWIP_INTERNAL

#if defined(ESP32)
  #define heatpumpSerial Serial1
  #define uartSerial Serial0 //not used, 10x header pin
  #define proxySerial Serial2
  #define HEATPUMPRX 17
  #define HEATPUMPTX 16
  #define PROXYRX 27
  #define PROXYTX 26
  #define ENABLEPIN 2 //RS485 not used so we redirect  GPIO from 5 to 2 
  //#define ENABLEOTPIN 4
  #define LEDPIN 42
  #define BOOTPIN 0
#include <WiFi.h>
#include <ESPmDNS.h>
#include <SoftwareSerial.h>
#endif

#include <DNSServer.h>
#include <WiFiUdp.h>
#include <ArduinoOTA.h>
#include <DNSServer.h>
#include <ArduinoJson.h>
#include "rs485modbus.h"//#485
#include "lwip/apps/sntp.h"
#include "src/common/timerqueue.h"
#include "src/common/stricmp.h"
#include "src/common/log.h"
#include "src/common/progmem.h"
#include "src/rules/rules.h"
#include "webfunctions.h"
#include "decode.h"
#include "commands.h"
#include "rules.h"
#include "version.h"

DNSServer dnsServer;

//to read bus voltage in stats
#ifdef ESP8266
ADC_MODE(ADC_VCC);
#endif

const byte DNS_PORT = 53;

#define SERIALTIMEOUT 4000 // wait until all 203 bytes are read, must not be too long to avoid blocking the code
EspSoftwareSerial::UART loggingSerial;// softwareSerial port to redirect message when Serial0 is used for MODBUS
Stream *SerialMonitor; //pointer to redirect messages to Serial or loggingSerial port

settingsStruct heishamonSettings;
uint32_t Wifiwskaz = 0; // wskaźnik zmian statusu wifi
String trasa={}; //do logowania zmian stanu wifi

uint32_t neoPixelState = 0; //running neoPixelState
bool inSetup; //bool to check if still booting
bool sending = false; // mutex for sending data
bool mqttcallbackinprogress = false; // mutex for processing mqtt callback

bool extraDataBlockAvailable = false; // this will be set to true if, during boot, heishamon detects this heatpump has extra data block (like K and L series do)

#define MQTTRECONNECTTIMER 30000 //it takes 30 secs for each mqtt server reconnect attempt
unsigned long lastMqttReconnectAttempt = 0;

unsigned long bootButtonNotPressed = 0;

#define WIFIRETRYTIMER 15000 // switch between hotspot and configured SSID each 10 secs if SSID is lost
unsigned long lastWifiRetryTimer = 0;
bool doInitialWifiScan = true; //we want an initial wifi scan to fill in the dropbox on the wifi settings page
int wifistats= WiFi.status();//to check phase of WiFi handshake
unsigned long lastRunTime = 0;
unsigned long lastOptionalPCBRunTime = 0;
unsigned long lastOptionalPCBSave = 0;
unsigned long lastProxyRead = 0;
bool proxydata_received = true;
unsigned long proxydata_timestamp = 0; 

unsigned long sendCommandReadTime = 0; //set to millis value during send, allow to wait millis for answer
unsigned long goodreads = 0;
unsigned long totalreads = 0;
unsigned long badcrcread = 0;
unsigned long badheaderread = 0;
unsigned long tooshortread = 0;
unsigned long toolongread = 0;
unsigned long timeoutread = 0;
float readpercentage = 0;
static int uploadpercentage = 0;

// instead of passing array pointers between functions we just define this in the global scope
#define MAXDATASIZE 255
char data[MAXDATASIZE] = { '\0' };
byte data_length = 0;

#ifdef ESP32
//for received proxied data
char proxydata[MAXDATASIZE] = { '\0' };
byte proxydata_length = 0;
#endif

// store actual data
char actData[DATASIZE] = { '\0' };
char actDataExtra[DATASIZE] = { '\0' };
char actOptData[OPTDATASIZE]  = { '\0' };

// log message to sprintf to
char log_msg[256];

// mqtt topic to sprintf and then publish to
char mqtt_topic[256];

static int mqttReconnects = 0;

// can't have too much in buffer due to memory shortage
#define MAXCOMMANDSINBUFFER 10

// buffer for commands to send
struct cmdbuffer_t {
  uint8_t length;
  byte data[128];
  bool cztaw_query; // true if this is a cztaw query
} cmdbuffer[MAXCOMMANDSINBUFFER];

static uint8_t cmdstart = 0;
static uint8_t cmdend = 0;
static uint8_t cmdnrel = 0;



// mqtt
WiFiClient mqtt_wifi_client;
PubSubClient mqtt_client;



bool firstConnectSinceBoot = true; //if this is true there is no first connection made yet

struct timerqueue_t **timerqueue = NULL;
int timerqueue_size = 0;

#define ETHC //&&&&&&&&&&&&&&&&&&&&&&&&&&&&&&&&&&&&&&&&&&&&&&&&&&&&&&&&&&&&&&&&&&&&&&&&&&&&&&&&&&&&&&&&&&&&&&&&&&&&&&&&&&&&&&&&&&&&&&&&&&&&&&&&&&
#ifdef ETHC
#define ETH_TYPE        ETH_PHY_W5500
#define ETH_ADDR         1
// ETH pins #485
#define ETH_CS          25
#define ETH_IRQ         33
#define ETH_RST         35

// SPI pins
#define ETH_SPI_SCK     14
#define ETH_SPI_MISO    34
#define ETH_SPI_MOSI    12

bool send_command(byte* command, int length,bool cztaw_query);
void setupOTA();
void send_optionalpcb_query();
void log_message(char* string);//#485
void send_initial_query();


//W5500 module start************************************************************************************************* */
void setupETH() {
  SPI.begin(ETH_SPI_SCK, ETH_SPI_MISO, ETH_SPI_MOSI);
    SerialMonitor->println("SPI started");  //#485
  if (ETH.begin(ETH_TYPE, ETH_ADDR, ETH_CS, ETH_IRQ, ETH_RST, SPI)) {
    //sethostname on ESP32 after eth.begin (!! for wifi is most be before...!!)
    String ETHname =heishamonSettings.wifi_hostname;//#485 
    ETHname="ETH"+ETHname;
    ETH.setHostname(ETHname.c_str());
    SerialMonitor->println("Ethernet started OK)");
  } else {
    SerialMonitor->println("Could not start ethernet. No ethernet module installed?");
  }
  if (ETH.hasIP()) {
    SerialMonitor->print("IP Address: ");
    SerialMonitor->println(ETH.localIP());
  } else {
    SerialMonitor->println("No IP address");
  }
}
#endif



/*
    check_wifi will process wifi reconnecting managing
*/
void check_wifi() {
  int wifistatus = WiFi.status();
  uint32_t WiFinow=wifistatus+WiFi.getMode()+WiFi.localIP()+WiFi.softAPgetStationNum();
  trasa="#";
if (WiFi.getMode() == WIFI_MODE_NULL)
{   setupWifi(&heishamonSettings);
lastWifiRetryTimer = millis();
//ESP.restart();;
}
bool Flash_Log = false; //enable Flash WiFi LOG 
if (Flash_Log) { //kill do weryfikacji czy dorobić ustawianie webowe
  if (!(Wifiwskaz==WiFinow)) {
    File checkModbLog= LittleFS.open("/modbus.log", "a+");
    trasa=trasa+"A";
    if (!checkModbLog) {
      SerialMonitor->println(F("Failed to open heishamon log file for appending"));
    }else{
      size_t filesize = checkModbLog.size();
      checkModbLog.close();
      if (filesize > 10000){
        trasa=trasa+"!";
      }
      time_t rawtime;
      rawtime = time(NULL);
      struct tm *timeinfo = localtime(&rawtime);
      char timestring[32];
      strftime(timestring, 32, "%c", timeinfo);
      checkModbLog= LittleFS.open("/modbus.log", "a+");
        if (checkModbLog ) {
          checkModbLog.printf("\nStat=%X  Mode=%X StNu=%X %s %s USED=%lu",wifistatus,WiFi.getMode(),WiFi.softAPgetStationNum(),WiFi.localIP().toString().c_str(), timestring, LittleFS.usedBytes());
          checkModbLog.close(); 
         }
      SerialMonitor->printf("\nStat=%X  Mode=%X StNu=%X %s %s",wifistatus,WiFi.getMode(),WiFi.softAPgetStationNum(),WiFi.localIP().toString().c_str(), timestring);
      Wifiwskaz=WiFinow ;
 }
  }
}

  if ((wifistatus != WL_CONNECTED) && (WiFi.localIP())) {
    trasa=trasa+"b";
    // special case where it seems that we are not connect but we do have working IP (causing the -1% wifi signal), do a reset.
    log_message(_F("WiFi just got disconnected, still have IP addres."));

  } else if ((wifistatus != WL_CONNECTED) || (!WiFi.localIP())) {
    /* if we are not connected to an AP  we must be in softAP so respond to DNS  */
    trasa=trasa+"C";
    if (heishamonSettings.hotspot) {
      dnsServer.processNextRequest();
      trasa=trasa+"d";
    }
    /* we need to stop reconnecting to a configured wifi network if there is a hotspot user connected
        also, do not disconnect if wifi network scan is active
    */
    if ((heishamonSettings.wifi_ssid[0] != '\0') && (wifistatus != WL_STOPPED) && (WiFi.scanComplete() != -1) && (WiFi.softAPgetStationNum() > 0)) {
      log_message(_F("WiFi lost, but softAP station connecting, so stop trying to connect to configured ssid..."));
      WiFi.mode(WIFI_AP);
      trasa=trasa+"E";
    }
    /*  only start this routine if timeout on
        reconnecting to AP and SSID is set
    */
    if ((heishamonSettings.wifi_ssid[0] != '\0') && ((unsigned long)(millis() - lastWifiRetryTimer) > WIFIRETRYTIMER)) {
      lastWifiRetryTimer = millis();
      trasa=trasa+"F";
      if (((WiFi.getMode() & WIFI_MODE_AP) == 0) && (heishamonSettings.hotspot)) {
        log_message(_F("WiFi lost, starting setup hotspot..."));
        WiFi.softAPConfig(apIP, apIP, IPAddress(255, 255, 255, 0));
        WiFi.softAP(_F("HeishaMon-Setup"));
        trasa=trasa+"g";
      }
      if ((wifistatus == WL_STOPPED or wifistatus == WL_IDLE_STATUS or wifistatus==WL_DISCONNECTED ) && (WiFi.softAPgetStationNum() == 0)) { //make sure we start STA again if it was stopped
        log_message(_F("Retrying configured WiFi, ..."));
        trasa=trasa+"H";
        WiFi.setSortMethod(WIFI_CONNECT_AP_BY_SIGNAL);
        WiFi.setScanMethod(WIFI_ALL_CHANNEL_SCAN); //select best AP with same SSID
        if (heishamonSettings.wifi_password[0] == '\0') {
          WiFi.begin(heishamonSettings.wifi_ssid);
          trasa="i";
        } else {
          WiFi.begin(heishamonSettings.wifi_ssid, heishamonSettings.wifi_password);
          trasa=trasa+"J";
        }
      }
    }
  }
#ifdef ETHC
  if (WiFi.localIP() || ETH.hasIP())    //WiFi or ETH connected and IP>0  check if active AP and disable if yes
#else
  if (WiFi.localIP())       //WiFi or ETH connected and IP>0  check if active AP and disable if yes
#endif
  {
    if (((WiFi.getMode() & WIFI_MODE_AP) != 0) && ((heishamonSettings.wifi_ssid[0] != '\0') || (!heishamonSettings.hotspot)) ) { //shutdown hotspot if it is running with configured SSID or if hotspot config is disabled
      log_message(_F("WiFi or ETH (re)connected, shutting down hotspot..."));
      WiFi.softAP("");
      WiFi.softAPdisconnect(true);
      trasa=trasa+"K";
    }
    if (firstConnectSinceBoot) {  // this should start only when softap is down or else it will not work properly so run after the routine to disable softap
      trasa=trasa+"l";
      firstConnectSinceBoot = false;
      lastMqttReconnectAttempt = 0;  //initiate mqtt connection asap
      setupOTA();
      MDNS.begin(heishamonSettings.wifi_hostname);
      MDNS.addService("http", "tcp", 80);
      SerialMonitor->print("Current IP = ");//#485
      SerialMonitor->println(WiFi.localIP());

      if (heishamonSettings.wifi_ssid[0] == '\0') {
        trasa=trasa+"M";
        log_message(_F("WiFi connected without SSID and password in settings. Must come from persistent memory. Storing in settings."));
        WiFi.SSID().toCharArray(heishamonSettings.wifi_ssid, 40);
        WiFi.psk().toCharArray(heishamonSettings.wifi_password, 40);
        JsonDocument jsonDoc;
        settingsToJson(jsonDoc, &heishamonSettings);  //stores current settings in a json document
        saveJsonToFile(jsonDoc, "config.json");     //save to config file
      }

      ntpReload(&heishamonSettings);
      logprintln_P(F("Try to syncing with ntp servers. Checking again in 5 minutes"));
      timerqueue_insert(300, 0, -6);
    }

    /*
       always update if wifi is working so next time on ssid failure
       it only starts the routine above after this timeout
    */
    lastWifiRetryTimer = millis();
  }

  if (doInitialWifiScan && (millis() > 15000)) {  //do a wifi scan a boot after 15 seconds
    trasa=trasa+"N";
    doInitialWifiScan = false;
    log_message(_F("Starting initial wifi scan ..."));
    WiFi.scanNetworks(true);
    SerialMonitor->print("_SCAN  ");
  }

  if ((strlen(trasa.c_str())>1)  and Flash_Log) {
    File checkModbLog = LittleFS.open("/modbus.log", "a+"); 
    if (checkModbLog ) {
      checkModbLog.printf("<%s>", trasa.c_str());
      checkModbLog.close(); 
    }
//    LOG_D("<WiFi trace %s\n>", trasa.c_str());
  }
}
/************************************************************************************************** */
void mqtt_reconnect()
{
  unsigned long now = millis();
  if ((lastMqttReconnectAttempt == 0) || ((unsigned long)(now - lastMqttReconnectAttempt) > MQTTRECONNECTTIMER)) { //only try reconnect each MQTTRECONNECTTIMER seconds or on boot when lastMqttReconnectAttempt is still 0
    lastMqttReconnectAttempt = now;
    if (mqttReconnects == 0) {
      log_message(_F("Connecting to mqtt server ..."));
    } else {
      log_message(_F("Reconnecting to mqtt server ..."));
    }
    char topic[256];
    sprintf(topic, "%s/%s", heishamonSettings.mqtt_topic_base, mqtt_willtopic);
    if (mqtt_client.connect(heishamonSettings.wifi_hostname, heishamonSettings.mqtt_username, heishamonSettings.mqtt_password, topic, 1, true, "Offline"))
    {
      mqttReconnects++;
      if (heishamonSettings.opentherm) {
        sprintf(topic, "%s/%s/#", heishamonSettings.mqtt_topic_base, mqtt_topic_opentherm_read);
        mqtt_client.subscribe(topic);
      }
      sprintf(topic, "%s/%s/#", heishamonSettings.mqtt_topic_base, mqtt_topic_commands);
      mqtt_client.subscribe(topic);
      sprintf(topic, "%s/%s/#", heishamonSettings.mqtt_topic_base, mqtt_topic_gpio);
      mqtt_client.subscribe(topic);      
      sprintf(topic, "%s/%s", heishamonSettings.mqtt_topic_base, mqtt_send_raw_value_topic);
      mqtt_client.subscribe(topic);
      sprintf(topic, "%s/%s", heishamonSettings.mqtt_topic_base, mqtt_willtopic);
      mqtt_client.publish(topic, "Online");

#ifdef ETHC
      if (ETH.hasIP()) {
      sprintf(topic, "%s/%s", heishamonSettings.mqtt_topic_base, mqtt_iptopic);
        mqtt_client.publish(topic, ETH.localIP().toString().c_str(), true);
        sprintf(topic, "%s/%s%s", heishamonSettings.mqtt_topic_base, mqtt_iptopic,"_ETH");
        mqtt_client.publish(topic, ETH.localIP().toString().c_str(), true);
      if (WiFi.localIP()) {
        sprintf(topic, "%s/%s%s", heishamonSettings.mqtt_topic_base, mqtt_iptopic,"_WiFi");
        mqtt_client.publish(topic, WiFi.localIP().toString().c_str(), true);
      }
      }
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
void loop() {
  //check boot button state
  checkBootButton();
  if (heishamonSettings.modbusOn) readModbus(); //#485
  //webserver function
  webserver_loop();

  // check wifi

  if (ETH.localIP()){
    WiFi.mode( WIFI_MODE_NULL );
  } 
  else check_wifi();
  delay(3);// bo check wifi coś żle działa  !!!!!!!!!!!!!!!!!!!!!!!!!!!!!!!!!!!!!!!!!!
 
  // Handle OTA first.s
  ArduinoOTA.handle();
  
  mqtt_client.loop();

  if (heishamonSettings.opentherm) {
    HeishaOTLoop(actData, mqtt_client, heishamonSettings.mqtt_topic_base);
  }

  readHeatpump();
  #ifdef ESP32
  if( (heishamonSettings.proxy) && (lastProxyRead-millis()) > 250){ //250ms between reads reduce errors to check
    readProxy();
    lastProxyRead=millis();
  }
  #endif

  if ((!sending) && (cmdnrel > 0)) { //check if there is a send command in the buffer
    log_message(_F("Sending command from buffer"));
    popCommandBuffer();
  }

  if (heishamonSettings.use_1wire) dallasLoop(mqtt_client, log_message, heishamonSettings.mqtt_topic_base);

  if (heishamonSettings.use_s0) s0Loop(mqtt_client, log_message, heishamonSettings.mqtt_topic_base, heishamonSettings.s0Settings);

  if ((!sending) && (!heishamonSettings.listenonly) && (heishamonSettings.optionalPCB) && ((unsigned long)(millis() - lastOptionalPCBRunTime) > OPTIONALPCBQUERYTIME) ) {
    lastOptionalPCBRunTime = millis();
    send_optionalpcb_query();
    if ((unsigned long)(millis() - lastOptionalPCBSave) > (1000 * OPTIONALPCBSAVETIME)) {  // only save each 5 minutes
      lastOptionalPCBSave = millis();
      if (saveOptionalPCB(optionalPCBQuery, OPTIONALPCBQUERYSIZE)) {
        log_message((char*)"Succesfully saved optional PCB data to flash!");
      } else {
        log_message((char*)"Failed to save optional PCB data to flash!");
      }
    }
  }

  // run the data query only each WAITTIME
  if ((unsigned long)(millis() - lastRunTime) > (1000 * heishamonSettings.waitTime)) {
    lastRunTime = millis();

#ifdef ETHC
    if ( (WiFi.isConnected()|| ETH.connected()) && (!mqtt_client.connected()) )
  #else
    if ( (WiFi.isConnected() ) && (!mqtt_client.connected()) )
  #endif
    {
      if (mqttReconnects > 0 ) log_message(_F("Lost MQTT connection!"));
      mqtt_reconnect();
    }

    //log stats
    if (totalreads > 0 ) readpercentage = (((float)goodreads / (float)totalreads) * 100);
    String message;
    message += F("Heishamon stats: Uptime: ");
    char *up = getUptime();
    message += up;
    free(up);
    message += F(" ## Free memory: ");
    message += getFreeMemory();
    message += F("% ## Free PSRAM: ");
    message += ESP.getFreePsram();
    message += F(" bytes ## Free heap: ");
    message += ESP.getFreeHeap();
    message += F(" bytes ## Wifi: ");
    message += getWifiQuality();
    message += F("% (RSSI: ");
    message += WiFi.RSSI();
    message += F(") WiFi (IP= "); 
    message += WiFi.localIP().toString();
    #ifdef ETHC
    message += F(") ## Ethernet: ");
    if (ETH.phyAddr() != 0) {        
      if (ETH.connected()) {
        if (ETH.hasIP()) {
          message += F("connected (IP= ");
          message += ETH.localIP().toString();
          message += F(")");
        } else {
          message += F("connected (no IP)");
        }
      } 
      else {
        message += F("not connected");
      }
    } else {
      message += F("not installed");
    }
    #endif
    message += F(" ## Mqtt reconnects: ");
    message += mqttReconnects;
    message += F(" ## Correct data: ");
    message += readpercentage;
    message += F("% Rules active: ");
    message += nrrules;
    log_message((char*)message.c_str());

//******************************************************************************************************* */
    String stats;
#ifdef ESP8266
    stats.reserve(384);
#endif
    stats += F("{\"uptime\":");
    stats += String(millis());
    stats += F(",\"voltage\":");
#if defined(ESP8266)
    stats += ESP.getVcc() / 1024.0;
#else
    stats += "3.3";
#endif
    stats += F(",\"free memory\":");
    stats += getFreeMemory();
    stats += F(",\"free heap\":");
    stats += ESP.getFreeHeap();
    stats += F(",\"wifi\":");
    stats += getWifiQuality();
    stats += F(",\"mqtt reconnects\":");
    stats += mqttReconnects;
    stats += F(",\"total reads\":");
    stats += totalreads;
    stats += F(",\"good reads\":");
    stats += goodreads;
    stats += F(",\"bad crc reads\":");
    stats += badcrcread;
    stats += F(",\"bad header reads\":");
    stats += badheaderread;
    stats += F(",\"too short reads\":");
    stats += tooshortread;
    stats += F(",\"too long reads\":");
    stats += toolongread;
    stats += F(",\"timeout reads\":");
    stats += timeoutread;
    stats += F(",\"version\":\"");
    stats += heishamon_version;
    stats += F("\",\"board\":\"");
#ifdef ESP8266
    stats += F("ESP8266");
#else
    stats += F("ESP32");
#endif
    stats += F("\",\"rules active\":");
    stats += nrrules;
    stats += F("}");
    sprintf_P(mqtt_topic, PSTR("%s/stats"), heishamonSettings.mqtt_topic_base);
    mqtt_client.publish(mqtt_topic, stats.c_str(), MQTT_RETAIN_VALUES);

    //websocket stats
    String ethernetStat {};
#ifdef ETHC
    if (ETH.phyAddr() != 0) {        
      if (ETH.connected()) {
        if (ETH.hasIP()) {
          ethernetStat = F("connected - IP: ");
          ethernetStat += ETH.localIP().toString();
          ethernetStat += F(")");
        } else {
          ethernetStat = F("connected - no IP");
        }
      } 
      else {
        ethernetStat = F("not connected");
      }
    } else {
      ethernetStat = F("not installed");
    }
#endif
    char *getuptime = getUptime();
    sprintf_P(log_msg, PSTR("{\"data\": {\"stats\": {\"wifi\": %d, \"ethernet\": \"%s\", \"memory\": %d, \"correct\": %.0f,\"mqtt\": %d,\"uptime\": \"%s\"}}}"), getWifiQuality(), ethernetStat.c_str(), getFreeMemory(), readpercentage, mqttReconnects, getuptime);
    free(getuptime);    
    websocket_write_all(log_msg, strlen(log_msg));        

    //get new data
    if (!heishamonSettings.listenonly && (cmdnrel==0)) send_panasonic_query();

    //Make sure the LWT is set to Online, even if the broker have marked it dead.
    sprintf_P(mqtt_topic, PSTR("%s/%s"), heishamonSettings.mqtt_topic_base, mqtt_willtopic);
    mqtt_client.publish(mqtt_topic, "Online");
  }

  timerqueue_update();
  #ifdef ESP32
  delay(1); // to keep watchdog happy
  #endif
}

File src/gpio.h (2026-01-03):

#if defined(ESP8266)
#define NUMGPIO 3
#include <ESP8266WiFi.h>
#include <ESP8266WiFiGratuitous.h>
#elif defined(ESP32)
#define NUMGPIO 6
#include <WiFi.h>
#include <ESPmDNS.h>
#include <Update.h>
#define relayOnePin 18
#define relayTwoPin 19
#endif

extern const char* mqtt_topic_gpio;

struct gpioSettingsStruct {
#if defined(ESP8266)
  unsigned int gpioPin[NUMGPIO] = {1, 3, 16};
  unsigned int gpioMode[NUMGPIO] = {INPUT_PULLUP, INPUT_PULLUP, INPUT_PULLUP};
#elif defined(ESP32)
  unsigned int gpioPin[NUMGPIO] = {4,5,18,19,22,32};
  unsigned int gpioMode[NUMGPIO] = {INPUT_PULLUP, INPUT_PULLUP, OUTPUT,OUTPUT, INPUT_PULLUP, INPUT_PULLUP, };
#endif
};

void setupGPIO(gpioSettingsStruct gpioSettings);
void mqttGPIOCallback(char* topic, char* value);

/*
ESP32 GPIO def https://lastminuteengineers.com/esp32-wroom-32-pinout-reference/?utm_content=cmp-true  
#define ENABLEPIN 2 //RS485 not used so we redirect  GPIO from 5 to 2  for compatibility
#define ENABLEOTPIN 4 // OpenTherm enable/disable
#define BOOTPIN 0 // Boot jumper

#define ETH_TYPE        ETH_PHY_W5500
#define ETH_ADDR        1

// ETH pins
#define ETH_CS          25
#define ETH_IRQ         33
#define ETH_RST         35

// SPI pins
#define ETH_SPI_SCK     14
#define ETH_SPI_MISO    34
#define ETH_SPI_MOSI    12

GPIO2 pin1 ESP_GPIO_12,  ESP_pin14  must be LOW during boot
GPIO2 pin2 ESP_GPIO_14,  ESP_pin13
GPIO2 pin3 ESP_GPIO_25,  ESP_pin10
GPIO2 pin4 ESP_GPIO_33,  ESP_pin9
GPIO2 pin5 ESP_GPIO_34,  ESP_pin6   must be Input
GPIO2 pin6 ESP_GPIO_35,  ESP_pin7   must be Input
GPIO2 pin7 GND,          ESP_pin1,15,38
GPIO2 pin8 +5V,         

GPIO1 pin1 ESP_GPIO_21   ESP_pin33 INPUT Schmidt trigger
GPIO1 pin2 ESP_GPIO_19   ESP_pin31
GPIO1 pin3 ESP_GPIO_18,  ESP_pin30

1Wire      ESP_GPIO32    ESP_pin8 INPUT

Counters pin1 GND
Counters pin2 ESP_GPIO_23 ESP_pin37 INPUT Schmidt trigger
Counters pin3 ESP_GPIO_22 ESP_pin36 INPUT Schmidt trigger

Boot pin1 ESP_GPIO_05 ESP_pin29 must be HIGH during boot 
Boot pin2 ESP_GPIO_00 ESP_pin5 INPUT must be HIGH during boot and LOW for programming
Boot pin3  GND 

SERIAL PORTS DESCRIPTION
Panasonic       ESP_GPIO_27 Rx   ESP_GPIO_26 Tx,  (hardware serial)
CZTAW1          ESP_GPIO_16 Rx   ESP_GPIO_17 Tx,  (hardware serial)
loggingSerial    ESP_GPIO_03 Rx   ESP_GPIO_1 Tx,   (hardware serial)
ModbusSerial    ESP_GPIO_21 Rx   ESP_GPIO_19 Tx,  (software serial)
*/

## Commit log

2023-09-13 Add files via upload
    Since not all esp32 modules (e. g. esp32u) have IO9 and IO10 outputs and lack of these outputs on DEV boards,
    I decided to redesign the board and adjust the program code. Now the IO9 and IO10 are replaced by IO27 and IO26 so it is possible provide tests on the DEV boards also.
    The program code is adapted to the change of the board and has fixes for the stability of work.
    Note: For the interface to work properly, it is necessary to connect it to a heat pump or a system that simulates the pump response.
    In the /piotools directory there is a simple program HP_Panasonic_Simul.ino that can be uploaded e. g. on Arduino Nano.
    Without communication from the heat pump, th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
    [HP_Panasonic_Simul.ino]
2023-10-31 Revert "mklittlefs.exe added to piotools"
    This reverts commit 5dc7a54dea29787a54537f84f260e2f0c12110cc.
    deleted: doc/HeishaMonBoth v 3_1 1.png
    [HeishaBoth.cpp]
2023-11-29 Add PCB pictures & set nodebug compilation option
2024-02-07 Improved S0 pulse counting, Fixed Vcc reading error with ESP32. Due to the lack of voltage measurement functionality on the ESP32 platform, the Vcc value has been set to 3.3 V for compatibility with 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
    [HP_Panasonic_Simul.ino, s0.cpp, webfunctions.h]
2025-01-29 Initial Ver 3.9 + Modbus
    [BotHeishaMonBoth.stl, TopHeishaMonBoth.stl]
2025-01-29 MOdbus doc changes
    [BotHeishaMonBoth.stl, HeishaBoth.stl]
2025-06-13 Impovement WiFi reconnect algoritm, added Modbus MQTT and JSON serialization, added new PCB and case design, updated documentation and firmware files.
    [BotHeishaMonBoth.stl, TopHeishaMonBoth.stl]
2026-01-03 Update version 3.9a and new PCB
    [MHMB_Bottom.stl, MHMB_Top.stl, partitions.csv]
2026-01-05 Doc Changes
    [BotHeishaMonBoth.stl, MHMB_Bottom.stl, MHMB_Top.stl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]
2026-10-12 Doc changes and new and old PCB compatibility
2026-10-29 Added the option for galvanic isolation between the interface and the heat pump. Added the option for galvanic isolation between the interface and MODBUS meters.
2026-11-11 3D Case New PCB upgrade
